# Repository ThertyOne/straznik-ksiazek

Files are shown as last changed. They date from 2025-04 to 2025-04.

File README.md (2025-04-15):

# Strażnik książek – Mechatroniczny Trzymacz Książek

Projekt realizowany w ramach kursu **Systemy elektroniczne w mechatronice** na Politechnice Wrocławskiej.

## 📚 Opis projektu

**Strażnik książek** to inteligentny trzymacz książek w formie figurki Iron-Mana, który reaguje na obecność użytkownika oraz warunki otoczenia. Urządzenie integruje różne technologie mechatroniczne, takie jak:

- Wykrywanie ruchu (czujnik PIR)
- Detekcja obecności książek (fotorezystor)
- Pomiar światła dziennego (fotorezystor)
- Podświetlenie LED (WS2812)
- Ruchoma głowa figurki (serwo MG90S)
- Efekty dźwiękowe (DFPlayer Mini + głośnik)

## ⚙️ Wykorzystane komponenty

- **Mikrokontroler**: Arduino Nano V3.0  
- **Czujniki**: PIR HC-SR505, 2x fotorezystor GL5616  
- **Wykonawcze**: serwomechanizm MG90S, listwa LED WS2812 (2x po 8 diod)  
- **Dźwięk**: DFPlayer Mini + głośnik 1W 8Ω  
- **Zasilanie**: 5V/2A (gniazdo DC barrel)  

## 💡 Funkcjonalność

1. Detekcja ruchu użytkownika aktywuje system.
2. Sprawdzana jest obecność książek oraz poziom światła dziennego.
3. Jeśli książki są obecne i jest ciemno:
   - Włączane jest podświetlenie LED.
   - Głowa figurki porusza się w stronę użytkownika.
   - Odtwarzany jest losowy dźwięk Iron-Mana (MP3 z karty SD).

System automatycznie się dezaktywuje przy braku ruchu.

## 🧠 Kod i biblioteki

Kod Arduino wykorzystuje następujące biblioteki:

- `Servo.h` – sterowanie serwem  
- `Adafruit_NeoPixel.h` – sterowanie LED WS2812  
- `SoftwareSerial.h` – komunikacja z DFPlayer Mini  
- `DFRobotDFPlayerMini.h` – obsługa odtwarzacza MP3

## 📦 Zawartość repozytorium

- `kod.ino` – kod źródłowy dla Arduino
- `schematy/` – schematy elektroniczne (.sch, .brd)
- `3d/` – modele 3D (.stl, .step)
- `bom.csv` – lista komponentów (Bill of Materials)
- `dokumentacja.pdf` – pełna dokumentacja projektowa
- `rysunki_złożeniowe.pdf` – wizualizacje montażu

## 👤 Autor

**Dominik Bukowicz**

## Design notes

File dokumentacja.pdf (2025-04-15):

## Politechnika Wroc lawska

## Wydzia l Elektroniki, Fotoniki i Mikrosystemów

# Stra żnik ksia żek

## Dokumentacja projektowa

Imie i nazwisko:
Dominik Bukowicz
Nr indeksu:
268519

Kurs:
Systemy elektroniczne w mechatronice

### Wroc law, kwiecień 2025

## Contents

1 Za lo żenia koncepcyjne i projektowe | 2
2 Schemat blokowy urzadzenia | 3
3 Opis dzia lania urzadzenia | 4
4 Opis symulacji konwertera logicznego (Rx) | 5
5 P lyta PCB realizujaca funkcje sterujaca (4 warstwy) | 7
6 Schemat blokowy kodu | 8
7 Instrukcja u żytkownika i uruchomienia | 10
8 Instrukcja serwisowa | 12
9 Widoki modelu 3D urzadzenia | 14
Dodatek A – Rysunki z lo żeniowe | 17
Dodatek B – Schemat elektroniczny uk ladu | 20
Dodatek C – Widok poszczególnych wartsw p lytki PCB | 22

## 1. Za lo żenia koncepcyjne i projektowe

Projekt ma na celu stworzenie mechatronicznego trzymacza ksiażek opartego o mikrokontroler Arduino Nano, inspirowanego postacia Iron-Mana. G lówne funkcjonalności to:

- Detekcja obecności użytkownika (PIR),
- Detekcja obecności ksiażek (fotorezystor),
- Detekcja świat la dziennego (fotorezystor),
- Oświetlenie LED (16 diod WS2812),
- Ruchoma g lowa (serwo MG90S),
- Odtwarzanie dźwieków (DFPlayer mini + g lośnik),
- System dezaktywuje sie, gdy nie ma ksiażek lub jest jasno.

Dla zapewnienia prawid lowej pracy ca lego systemu dobrano zasilanie 5V o wydajności pradowej do 2A poprzez z lacze typu DC barrel. Szacunkowe zużycie pradu przez poszczególne komponenty przedstawia Tabela 1. Maksymalny pobór pradu przy jednoczesnym dzia laniu serwomechanizmu, odtwarzacza DFPlayer oraz listw LED może wynie´sć nawet do 1,5–1,7 A, dlatego wybrano zasilacz zapewniajacy odpowiedni zapas bezpieczeństwa. Zastosowany zasilacz (5V/2A) zapewnia stabilno´sć pracy oraz możliwo´sć dalszej rozbudowy systemu.

Table 1: Szacowany pobór pradu przez komponenty systemu

Komponent | Pobór pradu
Arduino Nano V3.0 | do 200 mA
Serwo MG90S (w ruchu) | 120–250 mA (maks. 700 mA)
2x listwa LED WS2812 (16 diod) | ok. 220 mA (maks. do 960 mA)
DFPlayer Mini + g lośnik | do 200 mA
Czujnik PIR HC-SR505 | < 0,1 mA
Fotorezystory (2 szt., przez dzielniki napiecia) | pomijalne (µA)
Lacznie (typowo) Lacznie (szczytowo) | 800–950 mA do ok. 1,7 A

## 2. Schemat blokowy urzadzenia

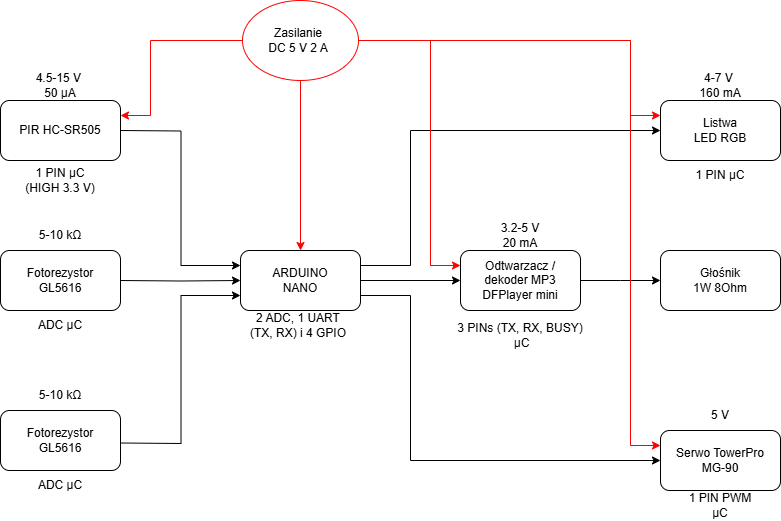
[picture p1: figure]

Figure 1: Schemat blokowy systemu

## 3. Opis dzia lania urzadzenia

Urzadzenie rozpoczyna swoje dzia lanie po wykryciu obecności użytkownika za pomoca czujnika ruchu PIR HC-SR505. Detekcja ruchu inicjuje sekwencje sprawdzania stanu otoczenia oraz warunków, w których aktywacja efektów ma sens i spe lnia za lożenia projektowe.
Pierwszym etapem po detekcji ruchu jest weryfikacja obecności ksiażek – realizowana przy pomocy fotorezystora (GL5616) umieszczonego w pokrywie trzymacza. W przypadku braku ksiażek urzadzenie nie podejmuje dalszych dzia lań.
Jeśli ksiażki sa obecne, system przechodzi do oceny warunków oświetleniowych – fotorezystor (GL5616) monitoruje poziom świat la dziennego. Jeżeli oświetlenie otoczenia przekracza ustalony próg (np. w ciagu dnia), funkcje urzadzenia pozostaja nieaktywne, by uniknać niepotrzebnego dzia lania.

W momencie, gdy spe lnione sa dwa podstawowe warunki:
- Obecno´sć ksiażek
- Brak świat la dziennego

Nastepuje aktywacja urzadzenia:

1. W lacza sie podświetlenie LED – listwa WS2812 w podstawie urzadzenia podświetla ksiażki efektownym, kolorowym świat lem (pomarańczowym).
2. Mechanizm obrotowy wprawia w ruch g lowe modelu Iron-Mana, wykonujac symboliczny gest interakcji.
3. DFPlayer Mini losowo wybiera i odtwarza jeden z wcześniej wgranych plików dźwiekowych w formacie MP3 – kwestie g losowe inspirowane postacia Iron-Mana (jedna z 5 losowych kwestii).

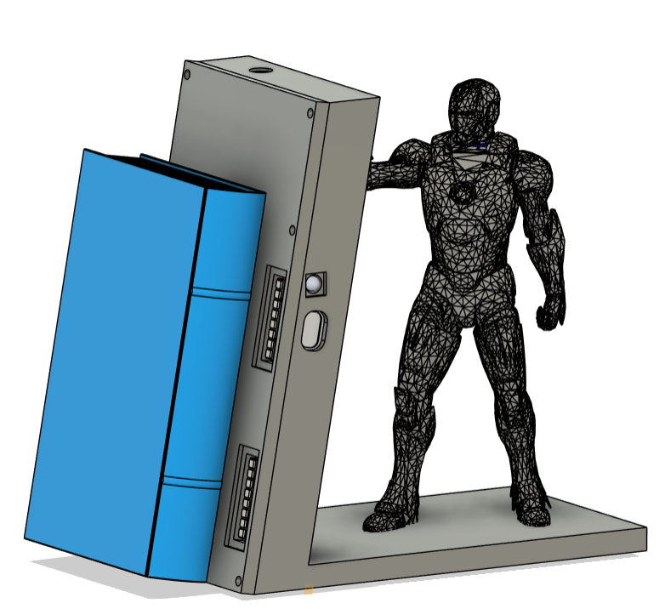
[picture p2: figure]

Figure 2: Schemat blokowy systemu

## 4. Opis symulacji konwertera logicznego (Rx)

W celu zapewnienia poprawnej komunikacji pomiedzy Arduino Nano (pracujacym z logika 5 V) a modu lem DFPlayer Mini (obs lugujacym poziomy logiczne 3,3 V), konieczne by lo dopasowanie poziomów napieć dla linii transmisji UART.
W celu konwersji logiki 3,3 V na logike 5 V zastosowano klasyczny uk lad logicznego konwertera poziomów napieć oparty na tranzystorze BSS138, dzia lajacy jako prze lacznik typu open-drain. Umożliwia on komunikacje pomiedzy urzadzeniami pracujacymi na różnych poziomach logicznych, zapewniajac niezawodna i bezpieczna dwukierunkowa transmisje danych bez ryzyka uszkodzenia modu lu DFPlayer Mini.
Dodatkowo, do jednostronnej konwersji (dla linii Tx Arduino → Rx DFPlayer) wykorzystano dzielnik napiecia zbudowany z rezystorów, który redukowa l napiecie z 5 V do oko lo 3,3 V.

### 4.1. Odbiór danych z DFPlayera:

Modu l DFPlayer Mini, oprócz odbierania komend sterujacych, może również wysy lać dane zwrotne przez swoja linie Tx (czyli Rx Arduino). Przyk ladowe dane to informacje o rozpoczeciu lub zakończeniu odtwarzania, kody b ledów (np. brak karty SD, nieprawid lowy format pliku), a także odpowiedzi na zapytania — np. aktualny poziom g lośności, numer odtwarzanego utworu czy liczba dostepnych plików.
Odbieranie tych danych może być kluczowe podczas debugowania kodu. Pozwala to na weryfikacje poprawności komunikacji UART, sprawdzenie, czy komendy sa prawid lowo interpretowane przez modu l oraz szybkie diagnozowanie problemów zwiazanych z dzia laniem DFPlayera lub karta pamieci. Dzieki temu możliwe jest precyzyjniejsze dostosowanie logiki programu do realnych warunków pracy uk ladu podczas debugownia kodu.
Poniżej znajduje sie schemat symulowanego uk ladu w programie LTspice, a także wynik przeprowadzonej symulacji, potwierdzajacy poprawno´sć dzia lania konwertera poziomów logicznych.

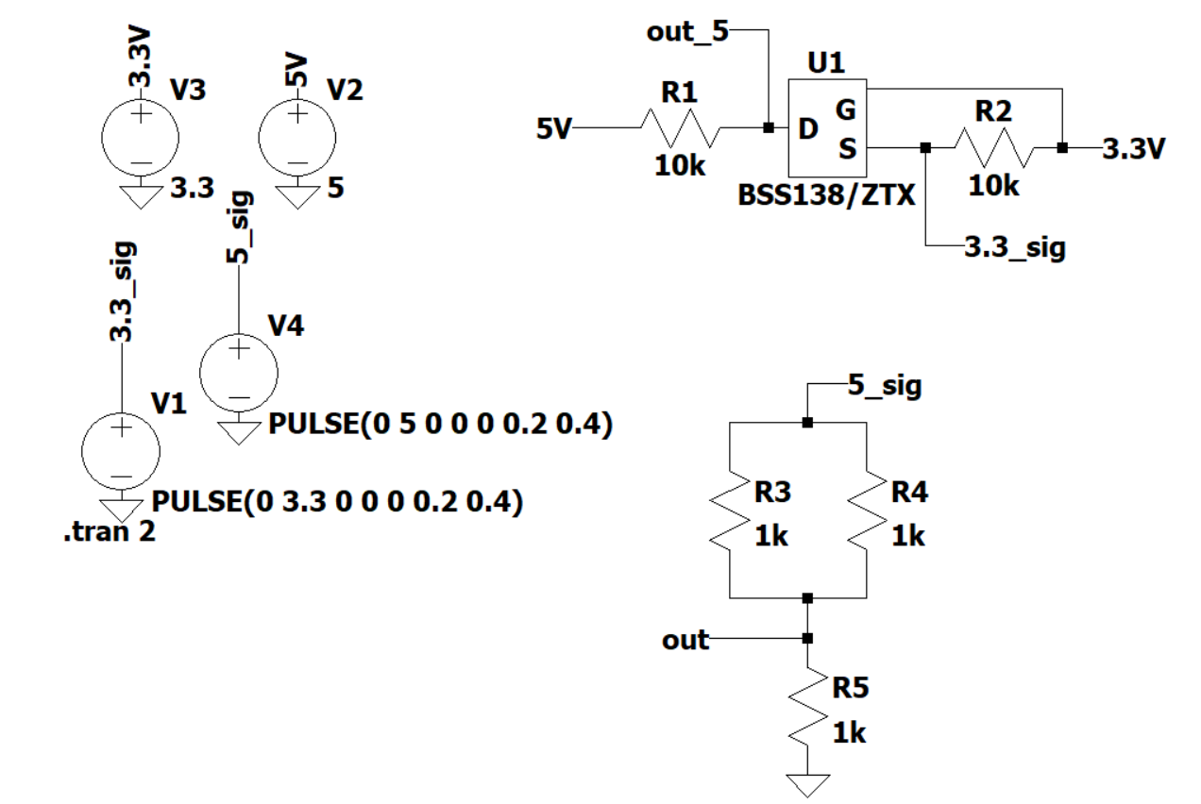
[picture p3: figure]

Figure 3: Symulacja konwertera logicznego Rx

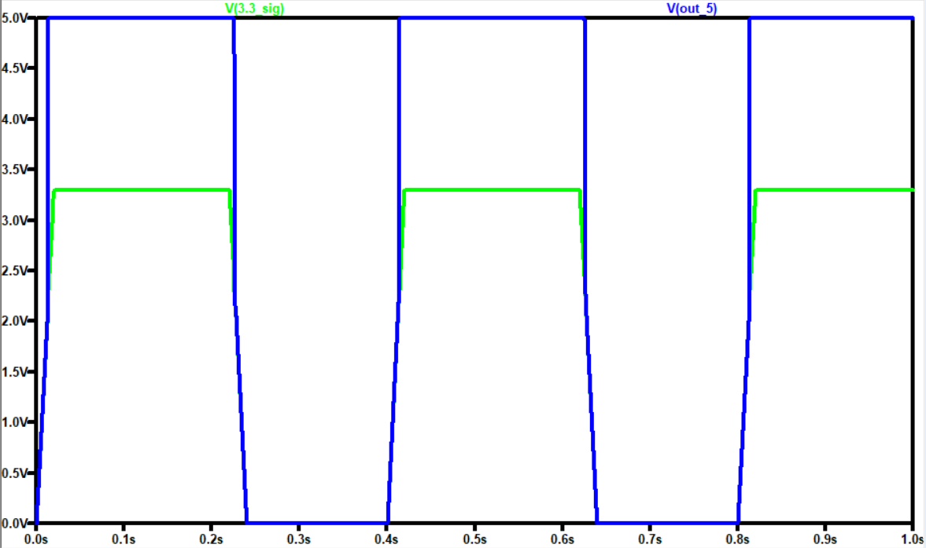
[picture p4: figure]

Figure 4: Wynik symulacji - napiecia Rx

## 5. P lyta PCB realizujaca funkcje sterujaca (4 warstwy)

W ramach integracji sygna lów z peryferiów oraz zapewnienia odpowiedniego reagowania systemu na zdarzenia zgodnie z za lożeniami projektowymi, zaprojektowano i wykonano czterowarstwowa p lytke PCB. Jej zadaniem jest po laczenie wszystkich kluczowych elementów systemu, takich jak mikrokontroler, czujniki, modu ly wykonawcze oraz komponenty zasilajace, w jeden spójny uk lad.
Cztery warstwy pozwoli ly na rozdzielenie sygna lów, zasilania oraz masy, co znaczaco poprawi lo integralno´sć sygna lu i zminimalizowa lo zak lócenia elektromagnetyczne (EMI). Zasilanie ca lego uk ladu realizowane jest poprzez zewnetrzny zasilacz 5V o wydajności pradowej 2A, co zapewnia odpowiednia rezerwe mocy nawet przy równoczesnym zasilaniu elementów o wiekszym poborze pradu, takich jak serwomechanizm MG90S, listwy LED WS2812 czy modu l DFPlayer Mini. Na p lytce zaprojektowano odpowiednie ścieżki i punkty rozdzia lu napiecia, a także uwzgledniono kondensatory filtrujace w celu stabilizacji pracy uk ladu i redukcji zak lóceń.
Na p lytce umieszczono z lacza do pod laczenia serwomechanizmu, listwy LED, czujnika PIR, fotorezystorów, DFPlayera oraz innych komponentów. Uwzgledniono również możliwo´sć programowania mikrokontrolera bez konieczności demontażu systemu oraz zaprojektowano p lytke tak, by umożliwia la latwy montaż mechaniczny wewnatrz obudowy urzadzenia.

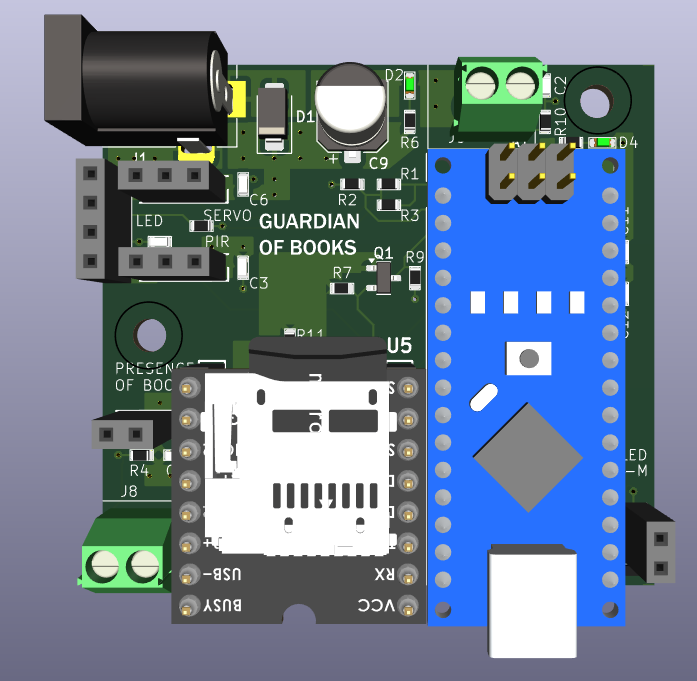
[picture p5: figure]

Figure 5: Model 3D p lytki obwodów drukowanych

## 6. Schemat blokowy kodu

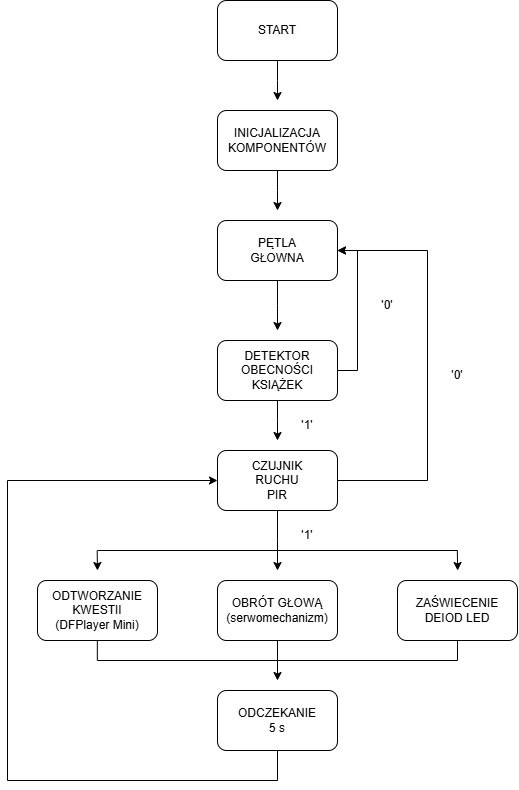
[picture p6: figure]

Figure 6: Schemat blokowy kodu

Kod wykorzystuje biblioteki:

- Servo.h – sterowanie serwem,
- Adafruit NeoPixel.h – sterowanie LED WS2812,
- SoftwareSerial.h – komunikacja z DFPlayer Mini,
- DFRobotDFPlayerMini.h – wybór i odtwarzanie plików MP3.

G lówne funkcje kodu:

- Odczyt z czujników (PIR, fotorezystory),
- Warunkowe w laczanie LED, serwa i dźwieku,
- Komunikacja z odtwarzaczem MP3.

## 7. Instrukcja u żytkownika i uruchomienia

Niniejsza instrukcja opisuje sposób poprawnego uruchomienia oraz użytkowania mechatronicznego trzymacza ksiażek w formie figurki Iron-Mana. Urzadzenie dzia la autonomicznie po prawid lowym zasileniu oraz spe lnieniu warunków środowiskowych.

1. Zasilanie: Pod lacz zasilacz 5V 2A do gniazda DC typu barrel znajdujacego sie z boku ścianki pionowej urzadzenia.
2. Karta microSD: Upewnij sie, że karta microSD zosta la poprawnie w lożona do gniazda DFPlayer Mini i zawiera poprawnie nazwane foldery:
- Nazwy folderów: 01, 02, 03, ...
- Pliki wewnatrz folderów: 001.mp3, 002.mp3, ...

Pliki dźwiekowe musza być zapisane w formacie MP3, WAV lub WMA.

3. Pozycjonowanie ksia żek: Umie´sć co najmniej jedna ksiażke na trzymaczu, zas laniajac czujnik obecności ksiażek (fotorezystor umieszczony w ściance trzymacza).
4. Uruchomienie systemu: Podejdź do urzadzenia w odleg lości poniżej 1 m. Czujnik PIR wykryje ruch użytkownika i aktywuje system.
5. Przebieg dzia lania po aktywacji:
- Sprawdzany jest poziom świat la dziennego — jeżeli jest ciemno, za laczane sa diody LED do oświetlenia ksiażek.
- Sprawdzana jest obecno´sć ksiażek – brak obecności dezaktywuje system.
- Serwomechanizm obraca g lowa Iron-Mana w kierunku użytkownika.
- DFPlayer Mini odtwarza losowa kwestie Iron-Mana z dostepnych plików.
6. Dezaktywacja: Po wykryciu braku ruchu w otoczeniu (ok. 5 sekund bez sygna lu z czujnika PIR), system automatycznie przechodzi w stan spoczynku:
- Wy laczane jest oświetlenie LED,
- Serwomechanizm wraca do pozycji poczatkowej,
- Odtwarzanie zostaje zakończone.
7. Bezpieczne wy laczenie: Aby wy laczyć system, należy od laczyć zasilacz 5V DC. Nie należy wy laczać urzadzenia przez od laczanie pojedynczych przewodów ani przez gwa ltowne ruchy.
8. Uwaga: Podczas aktualizacji oprogramowania (wgrywania kodu do Arduino Nano przez USB), zewnetrzne zasilanie 5V musi być od laczone, aby uniknać uszkodzenia portu USB lub mikrokontrolera.

Zalecenia dla u żytkownika:

- Nie należy narażać urzadzenia na dzia lanie wilgoci ani wysokich temperatur.

- Nie należy manipulować przy czujnikach ani przewodach podczas dzia lania systemu.
- Ruchome elementy (np. g lowa figurki) powinny mieć zapewniona przestrzeń do swobodnego poruszania sie.
- System nie jest przystosowany do pracy ciag lej – zaleca sie jego wy laczenie na noc lub podczas d luższej nieobecności.

## 8. Instrukcja serwisowa

Urzadzenie wymaga okresowej kontroli pod wzgledem poprawności dzia lania oraz czystości po laczeń mechanicznych i elektrycznych. Poniżej przedstawiono zalecane czynności serwisowe oraz instrukcje aktualizacji lub debugowania kodu na mikrokontrolerze.

### 8.1. Elementy wymagajace kontroli

- Serwomechanizm MG90S – należy upewnić sie, że mechanicznie nie jest zablokowany oraz że obrót odbywa sie p lynnie.
- Listwy LED WS2812 – należy sprawdzić, czy wszystkie diody świeca sie prawid lowo. W przypadku losowego migania może być konieczne sprawdzenie rezystora szeregowego na linii danych (330 Ω).
- DFPlayer Mini – jeżeli nie odtwarza dźwieków, należy upewnić sie, że karta microSD jest poprawnie sformatowana (FAT32), zawiera odpowiednie pliki w odpowiednich folderach oraz że linie komunikacyjne TX/RX nie sa uszkodzone.
- Czujniki PIR i fotorezystory – moga ulec zabrudzeniu lub uszkodzeniu mechanicznemu. Warto okresowo sprawdzić ich reakcje na zmiany w otoczeniu (ruch/świat lo).
- Po laczenia GND i 5V – należy skontrolować, czy wszystkie przewody zasilajace i masy sa dobrze przylutowane lub pewnie umocowane w z laczach.
- Zasilanie 5V (2A) – w przypadku niestabilnego dzia lania uk ladu (np. restart Arduino, niedzia lajace diody LED) należy zmierzyć napiecie wyjściowe zasilacza oraz sprawdzić, czy jego wydajno´sć pradowa jest wystarczajaca.
- Zasilanie - należy sprawdzić czy wszystkie diody sygnalizujace napiecie zasilania świeca prawid lowo (5V, 5V Arduino, 3.3V).

### 8.2. Procedura ladowania lub debugowania kodu

Do wgrania nowego kodu na Arduino Nano lub jego debugowania należy:

1. Od laczyć zewnetrzne zasilanie 5V DC!
2. Pod laczyć komputer do Arduino Nano za pomoca kabla USB (microUSB).
3. W środowisku Arduino IDE wybrać odpowiedni port COM oraz p lytke (Arduino Nano, procesor ATmega328P, bootloader ”Old Bootloader” jeśli wymagany).
4. Za ladować kod klikajac Upload.
5. Po zakończeniu wgrywania od laczyć kabel USB i dopiero wtedy ponownie pod laczyć zasilanie 5V DC.

Uwaga: Jednoczesne pod laczenie zasilania zewnetrznego oraz USB może prowadzić do uszkodzenia komputera lub p lytki Arduino, ponieważ może doj´sć do konfliktu napieć na linii VCC.

### 8.3. Uwagi końcowe

W razie konieczności wymiany jakiegokolwiek elementu należy zachować szczególna ostrożno´sć podczas lutowania oraz unikać zwarć przy ponownym montażu. Wszystkie naprawy należy wykonywać przy od laczonym zasilaniu. Zaleca sie przeprowadzenie pe lnego testu systemu po każdej naprawie lub aktualizacji oprogramowania.

## 9. Widoki modelu 3D urzadzenia

Model 3D przedstawia figure Iron Mana o wysokości 25–30 cm, trzymajaca pionowa ścianke pe lniaca funkcje podpórki na ksiażki. Postać ma wyciagnieta d loń ustawiona pod katem oko lo 90 stopni, co zapewnia stabilne podparcie konstrukcji. Wzd luż ramienia zosta l zaprojektowany tunel umożliwiajacy poprowadzenie przewodów zasilajacych i sterujacych do serwomechanizmu, ukrytego wewnatrz korpusu figury.
G lowa postaci jest ruchoma w zakresie 0–90 stopni dzieki zastosowaniu serwomechanizmu MG90S, zintegrowanego z korpusem. Wewnatrz g lowy wydrażono gniazdo dopasowane do profilu zebatki serwa, co umożliwia bezpośrednie po laczenie z jego osia – bez potrzeby stosowania dodatkowych mocowań. Ca ly mechanizm zosta l dyskretnie ukryty pod elementem imitujacym bark i szyje, co pozwala zachować spójno´sć wizualna modelu i jednocześnie zapewnia precyzje oraz stabilno´sć ruchu.
Pionowa ścianka wspierajaca ksiażki jest zintegrowana z podstawa, w której przewidziano miejsce na p lytke PCB oraz inne komponenty elektroniczne. Pokrywa ścianki zawiera otwory na diody LED oraz czujnik obecności ksiażek, a ca lo´sć zamyka estetyczna pokrywka mocowana za pomoca śrub. Projekt laczy elementy dekoracyjne z praktycznymi rozwiazaniami technicznymi, tworzac zarówno funkcjonalny, jak i wizualnie atrakcyjny element wyposażenia.

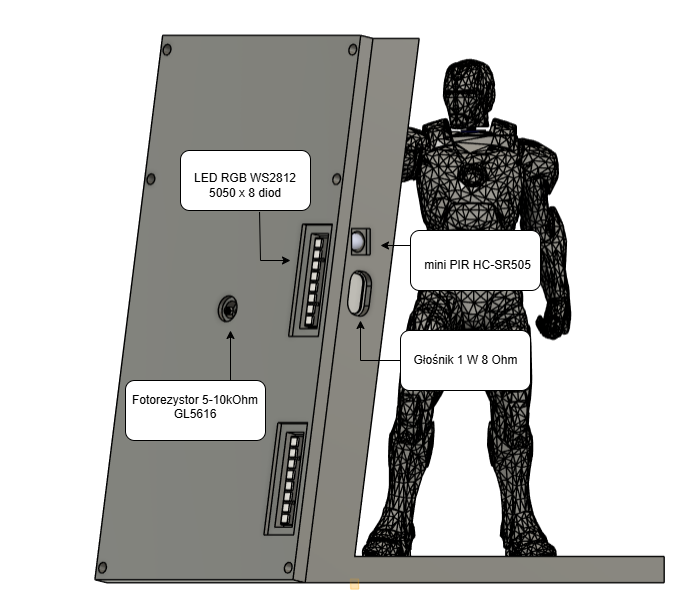
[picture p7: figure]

Figure 7: Widok modelu 3D z objaśnieniem elementów projektu (1)

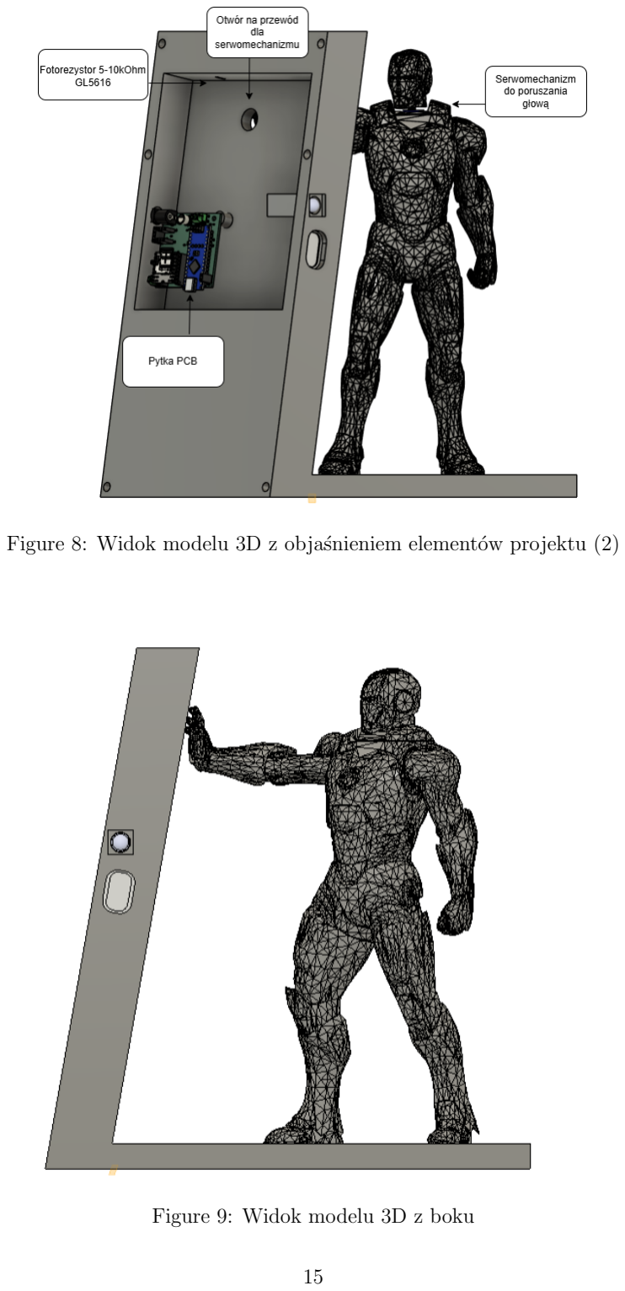
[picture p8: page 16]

Figure 8: Widok modelu 3D z objaśnieniem elementów projektu (2)

Figure 9: Widok modelu 3D z boku

## Za laczniki

- Plik BOM (.csv),
- Kod programu (.ino),
- Pliki 3D (.stl, .step),
- Schematy elektryczne (.sch, .brd),
- Biblioteki wykorzystanych elementów elektronicznych (.kicadsym, .pretty),
- Noty katalogowe kluczowych elementów (.pdf),
- Rysunki z lożeniowe (.pdf).

## Dodatek A – Rysunki z lo żeniowe

Schemat montażowy uk ladu zosta l przedstawiony na ilustracji 10, bedacej wizualizacja modelu 3D p lytki PCB. Na rysunku zaznaczono miejsca pod laczenia wszystkich g lównych przewodów sygna lowych oraz zasilajacych. Czerwone kwadraty na modelu oznaczaja dedykowane punkty GND dla poszczególnych peryferiów.

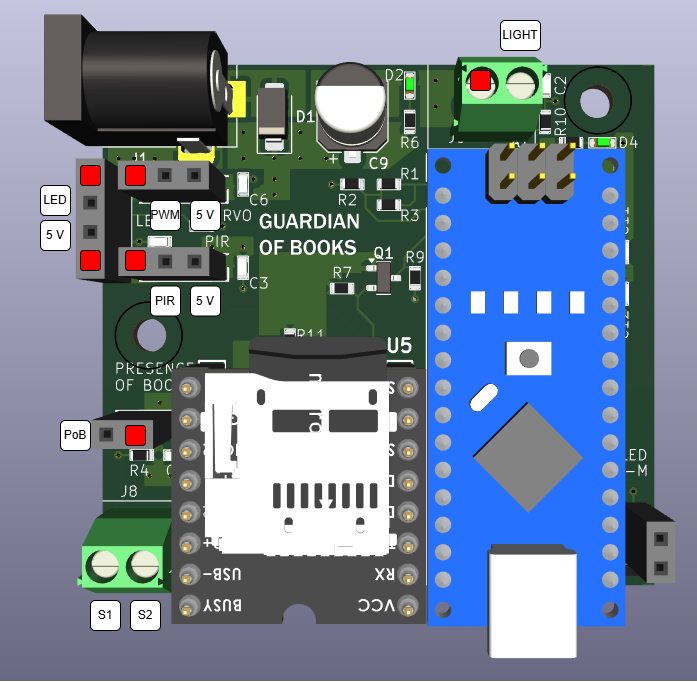
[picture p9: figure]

Figure 10: Model 3D PCB z oznaczeniami wyprowadzeń

W poniższej tabeli przedstawiono zestawienie peryferiów oraz opis ich wymaganych wyprowadzeń:

Peryferium | Wyprowadzenia
Serwo MG90S Listwy LED WS2812 (2x) Czujnik PIR HC-SR505 G lośnik 1W 8Ω Fotorezystor (ksiażki) Fotorezystor (świat lo dzienne) | PWM (D9), 5V, GND LED (D6), 5V, GND PIR (D2), 5V, GND SPK1, SPK2 PoB, GND LIGHT, GND

Table 2: Zestawienie wyprowadzeń dla peryferiów

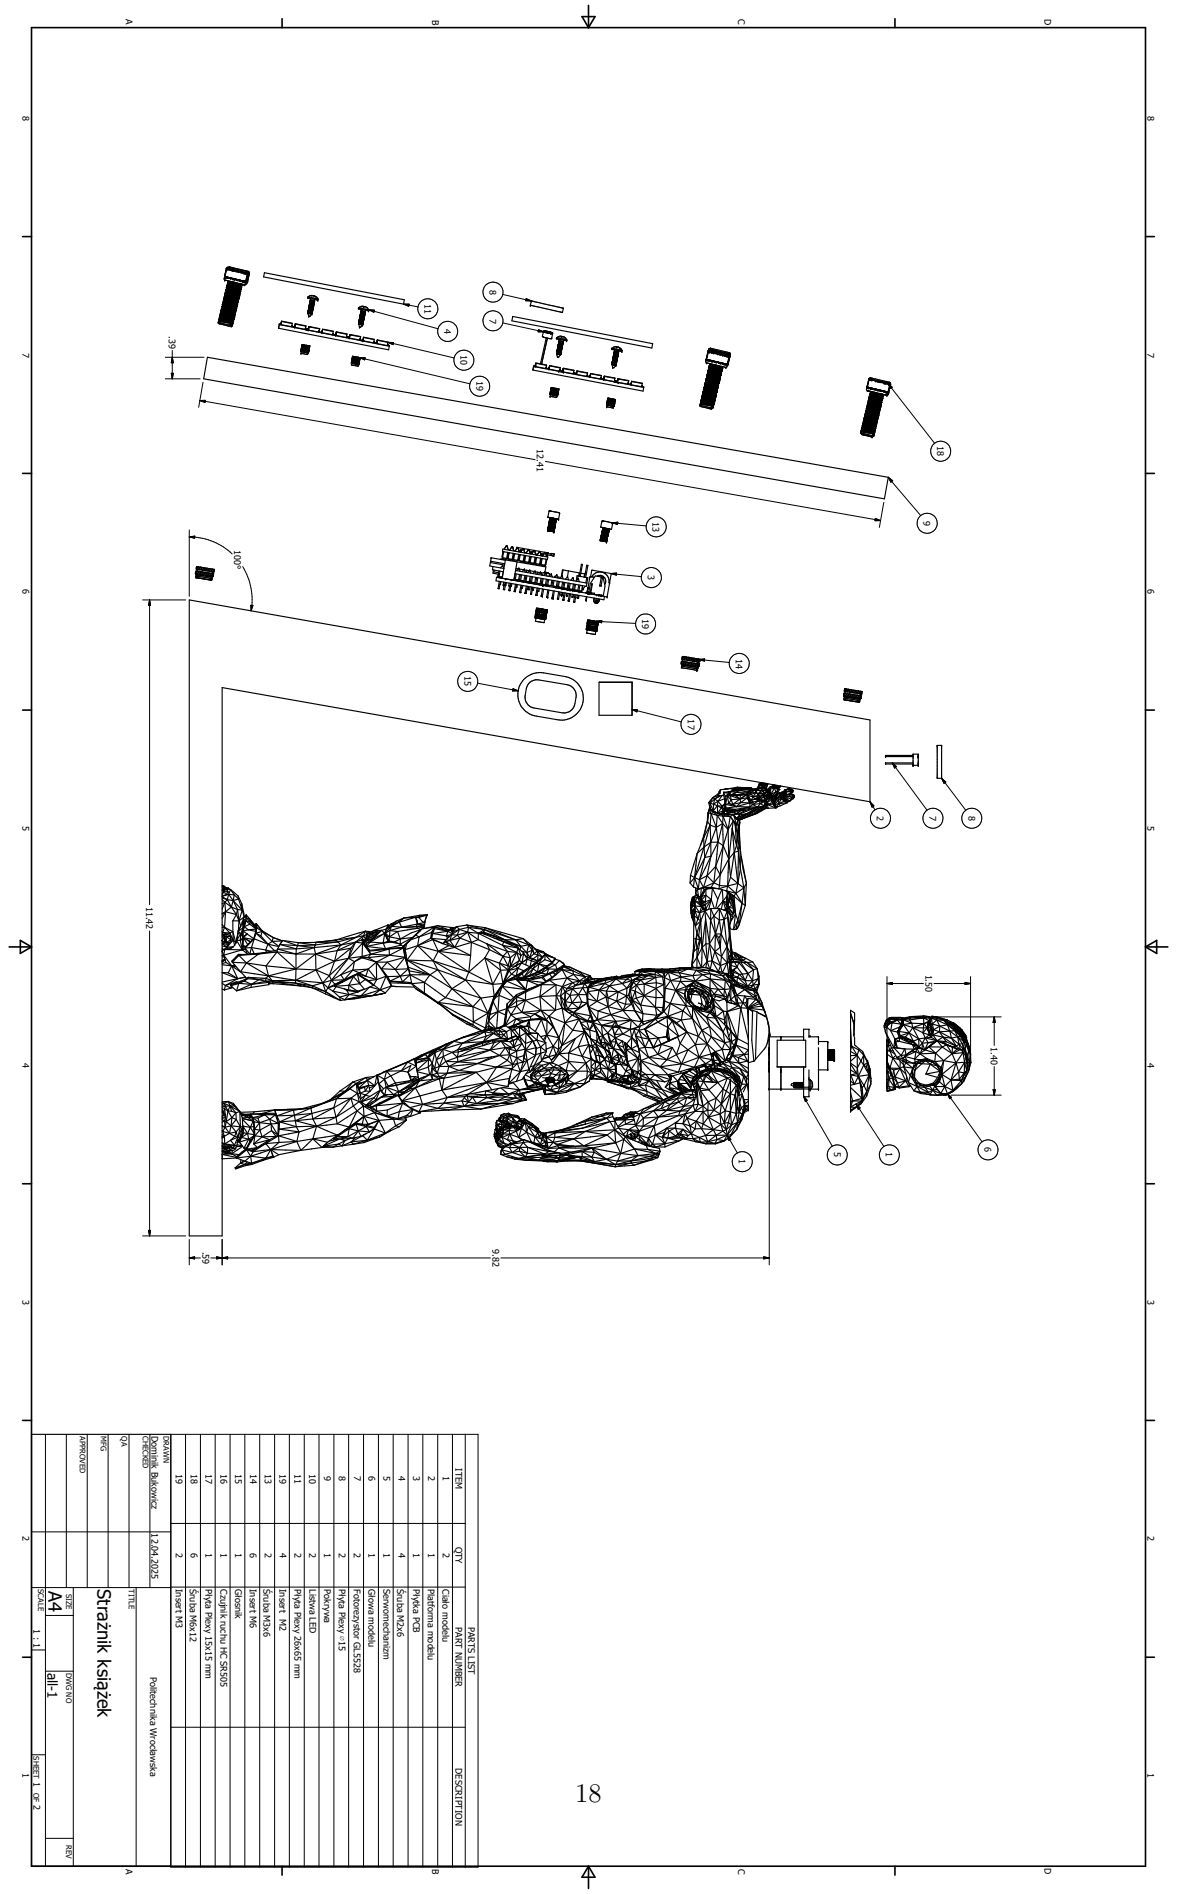
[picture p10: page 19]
PARTS LIST; Ciało modelu 2 1; Platforma modelu 1 2; Płytka PCB 1 3; Śruba M2x6 4 4; Serwomechanizm 1 5; Głowa modelu 1 6; Fotorezystor GL5528 2 7; Płyta Plexy ∅15 2 8; Pokrywa 1 9; Listwa LED 2 10; Insert M2 4 19; Śruba M3x6 2 13; Insert M6 6 14; Głosnik 1 15; Śruba M6x12 6 18; Insert M3 2 19; SHEET 1 OF 2; APPROVED; MFG; CHECKED; Dominik Bukowicz 12.04.2025; DRAWN; all-1; DWG NO; Strażnik książek; TITLE; A4 SIZE; SCALE; Politechnika Wrocławska; REV

Płyta Plexy 15x15 mm 1 17

Czujnik ruchu HC SR505 1 16

Płyta Plexy 26x65 mm 2 11

DESCRIPTION PART NUMBER QTY ITEM

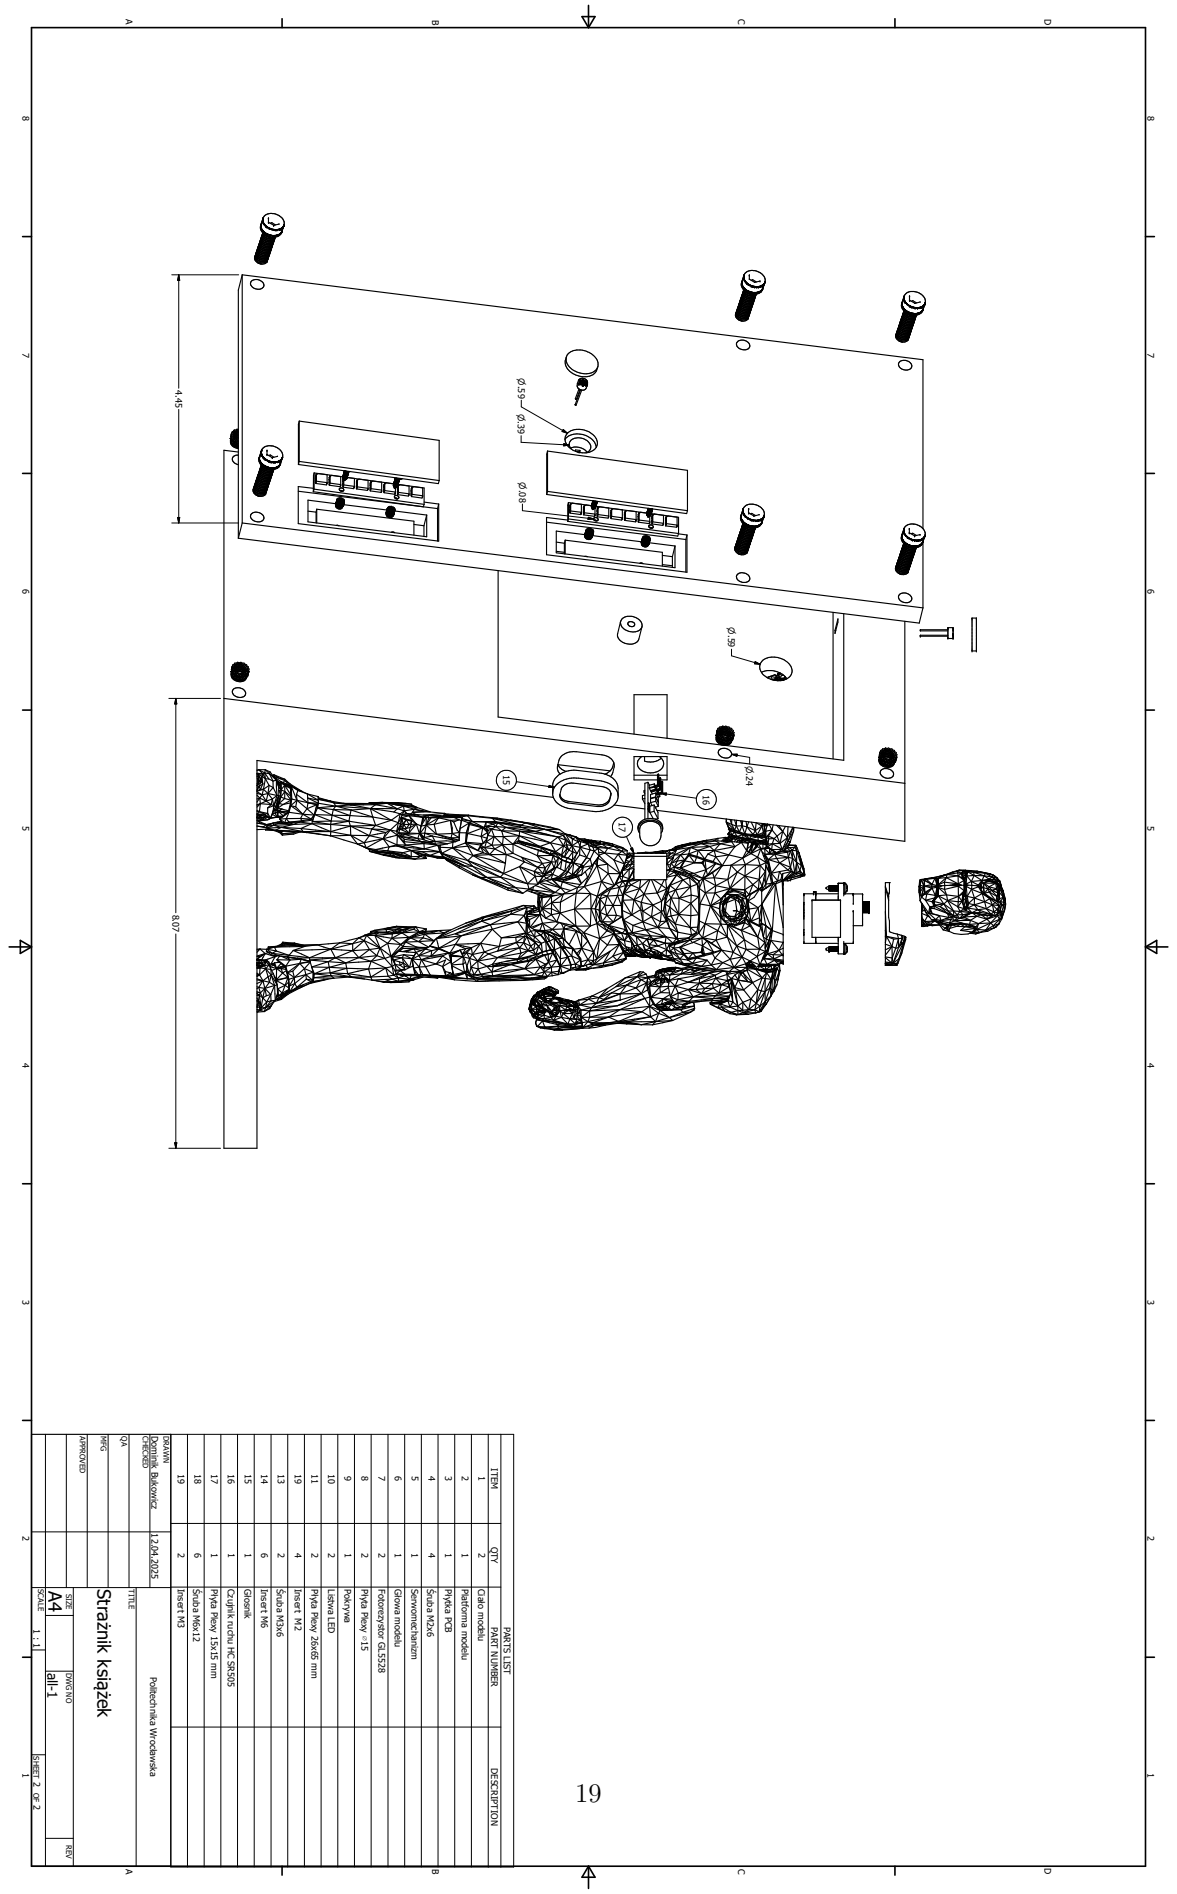
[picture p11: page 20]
SHEET 2 OF 2; APPROVED; MFG; CHECKED; Dominik Bukowicz 12.04.2025; DRAWN; all-1; DWG NO; Strażnik książek; TITLE; A4 SIZE; SCALE; Politechnika Wrocławska; REV; PARTS LIST; Ciało modelu 2 1; Platforma modelu 1 2; Płytka PCB 1 3; Śruba M2x6 4 4; Serwomechanizm 1 5; Głowa modelu 1 6; Fotorezystor GL5528 2 7; Płyta Plexy ∅15 2 8; Pokrywa 1 9; Listwa LED 2 10; Insert M2 4 19; Śruba M3x6 2 13; Insert M6 6 14; Głosnik 1 15; Śruba M6x12 6 18; Insert M3 2 19

Płyta Plexy 15x15 mm 1 17

Czujnik ruchu HC SR505 1 16

Płyta Plexy 26x65 mm 2 11

DESCRIPTION PART NUMBER QTY ITEM

## Dodatek B – Schemat elektroniczny uk ladu

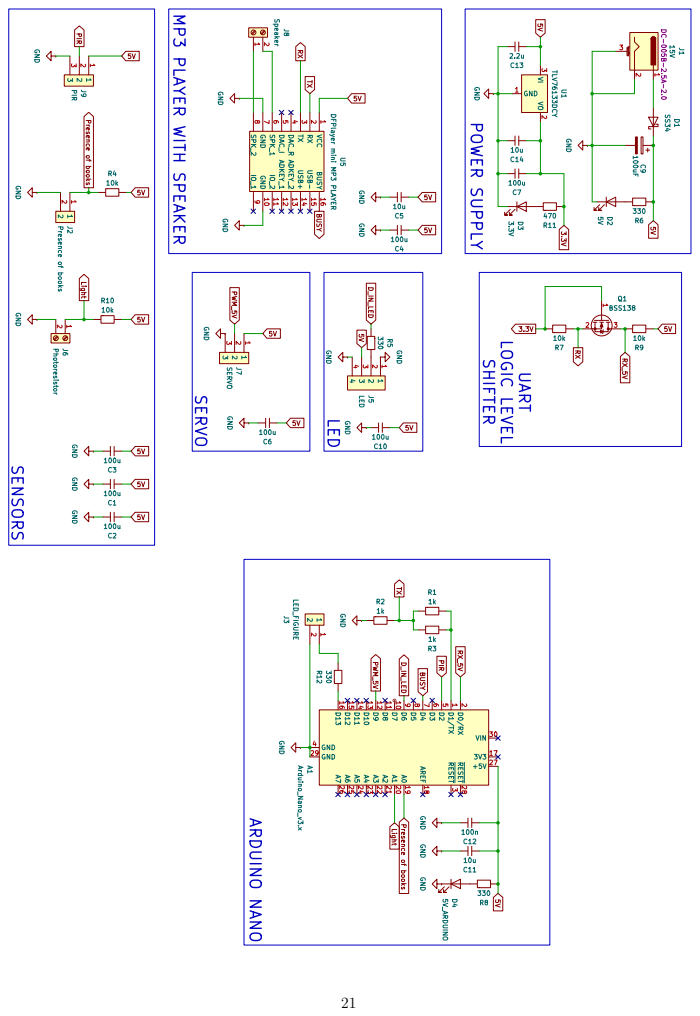
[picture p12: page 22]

## Dodatek C – Widok poszczególnych wartsw p lytki PCB

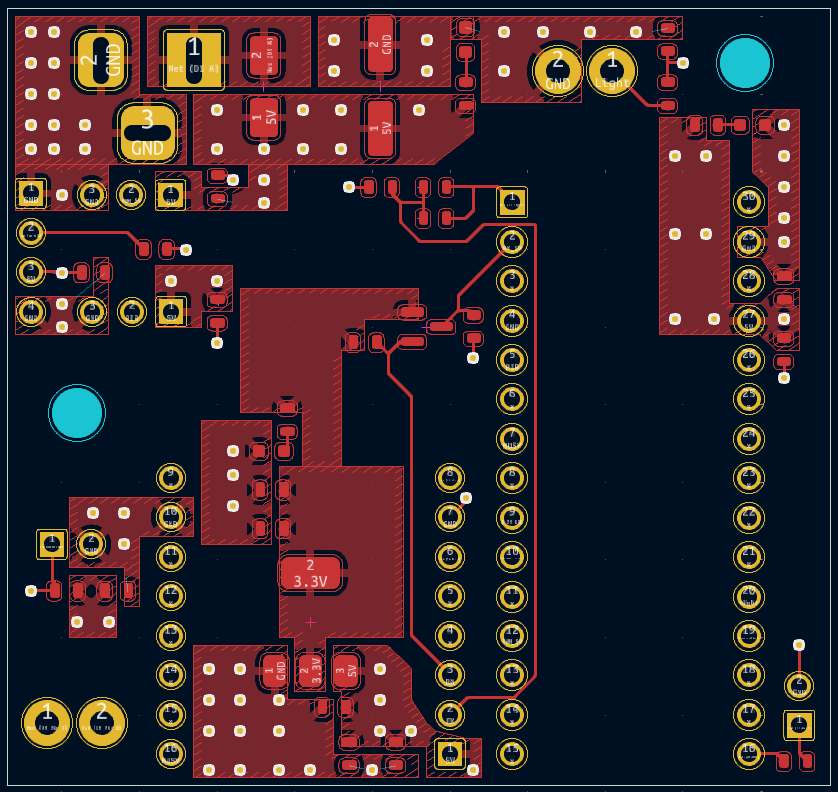
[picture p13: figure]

Figure 11: Warstwa sygna lowa (top)

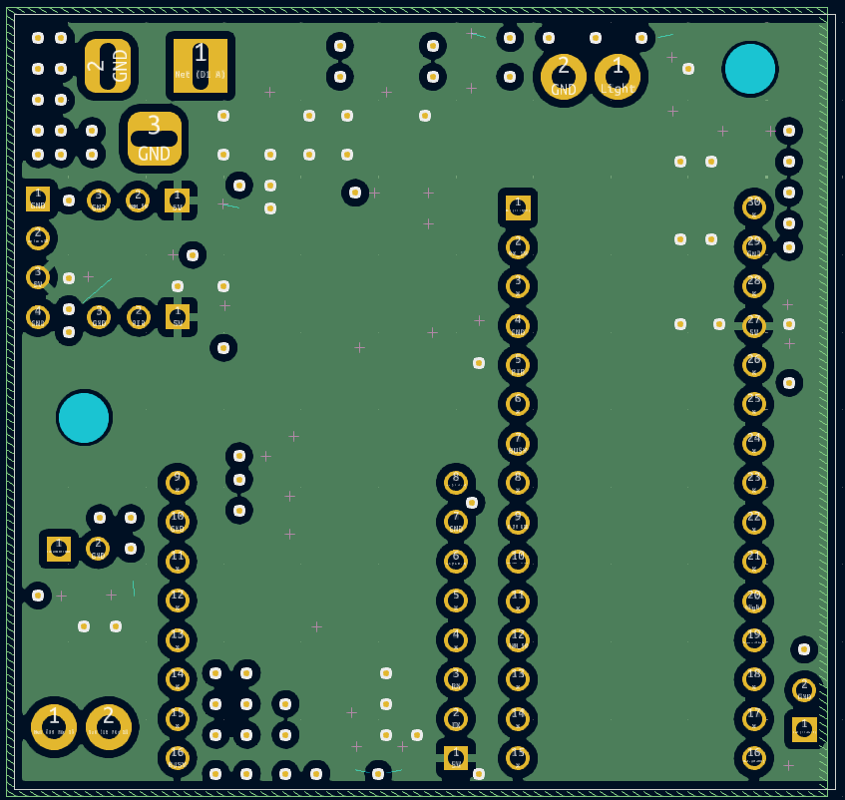
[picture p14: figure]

Figure 12: Warstwa zasilajaca 5V

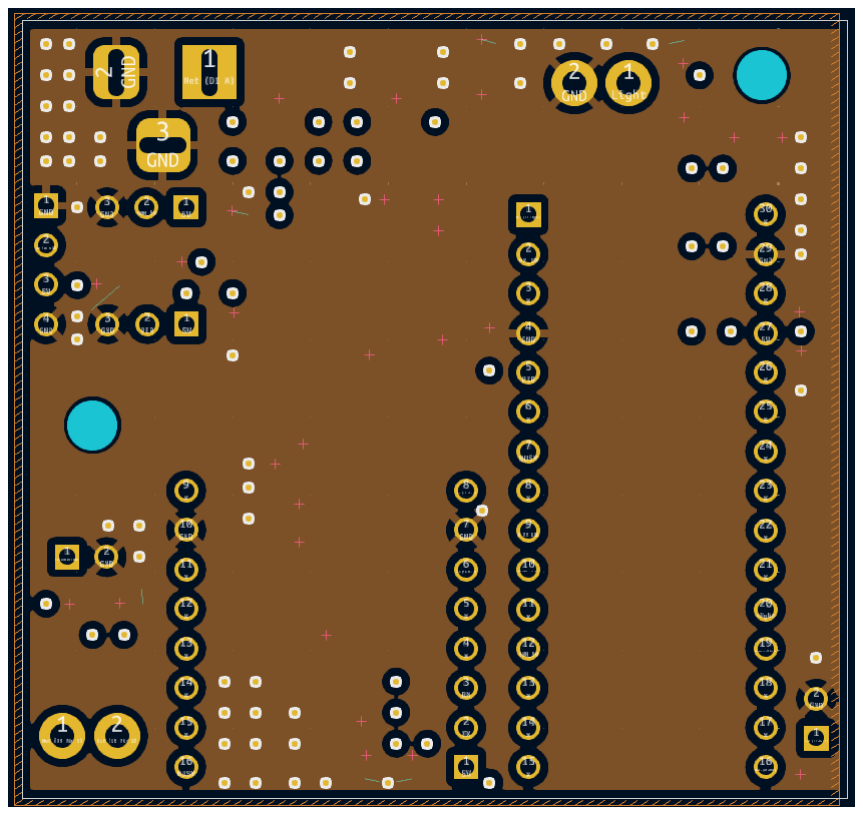
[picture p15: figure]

Figure 13: Warstwa GND

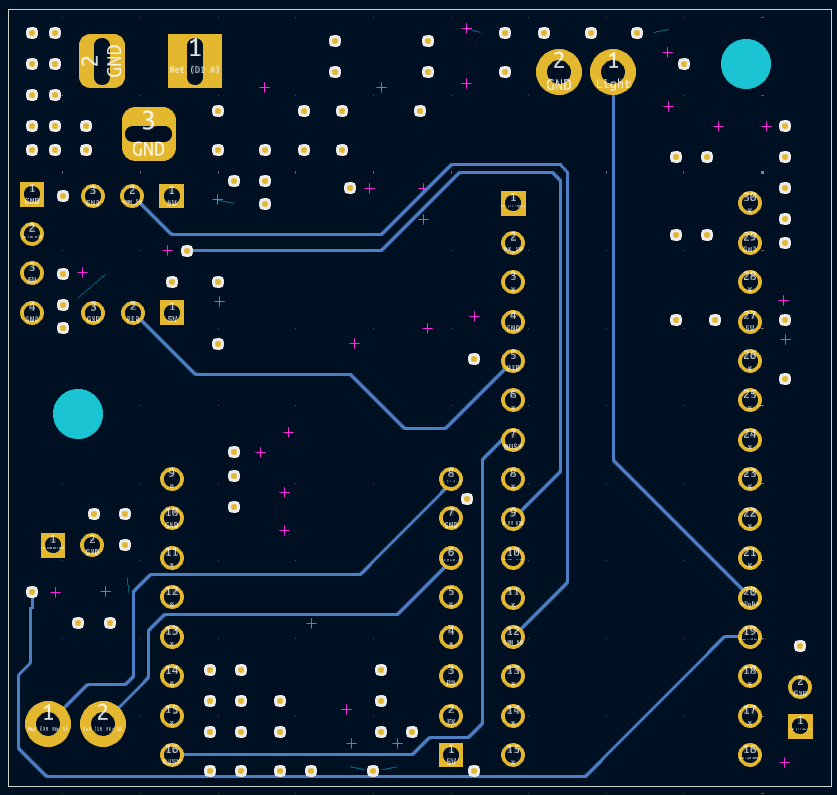
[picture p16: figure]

Figure 14: Warstwa sygna lowa (bottom)

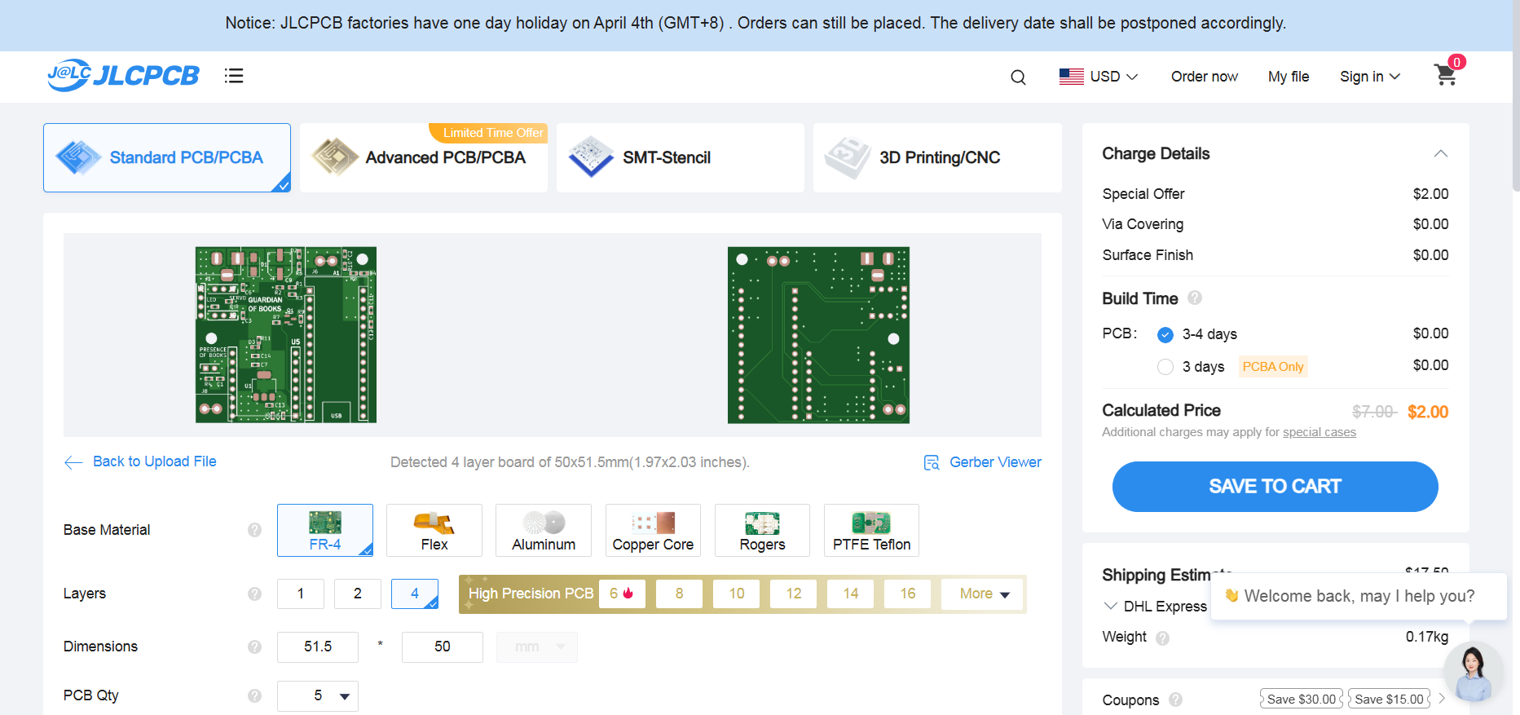
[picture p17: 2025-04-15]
JPCLB _zamownie.png

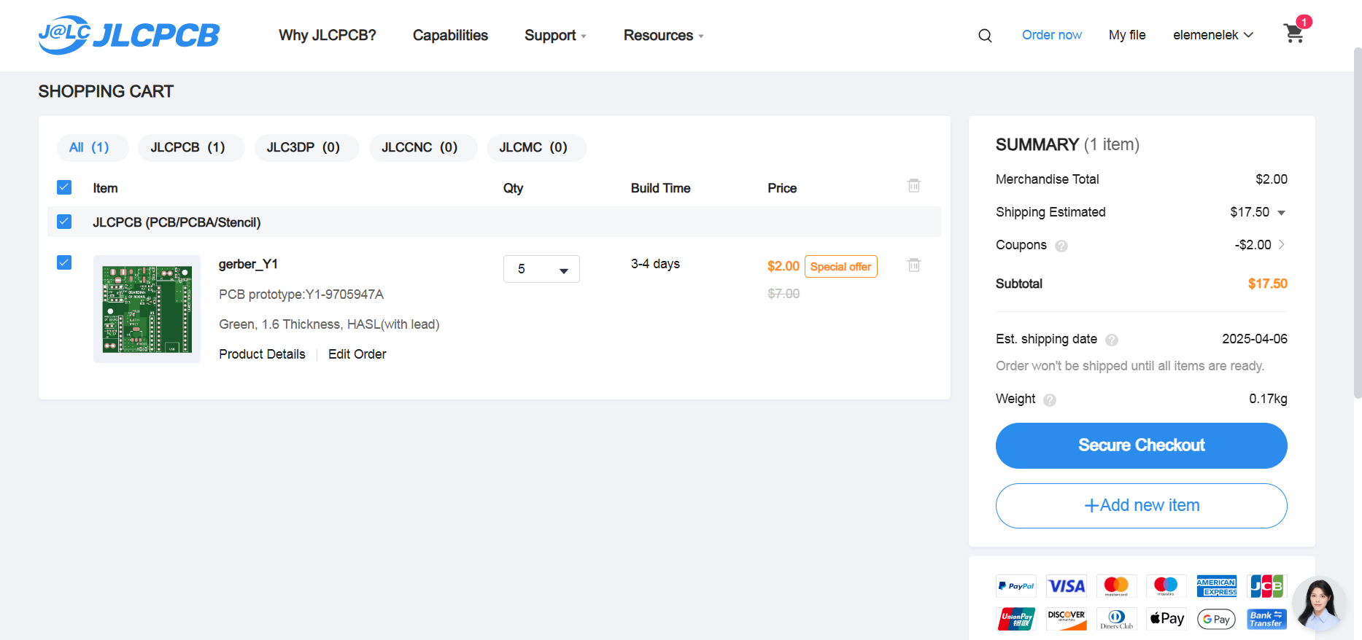
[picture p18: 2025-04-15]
JPCLB_z_wysylka.png

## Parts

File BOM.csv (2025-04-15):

Nr. | Oznaczenie | Footprint | Ilo?? | Nazwa / numer seryjny | Warto?? | Tolerancja | Cena za szt. [z?] | URL
1 | R11 | res_0603 | 1 | RC0603FR-07470RP | 470 | ±1% | 0,39 | https://www.digikey.pl/pl/products/detail/yageo/RC0603FR-07470RP/4935414?productid=4935414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
2 | R12,R6,R5,R8 | res_0603 | 4 | RC0603JR-13330RL | 330 | ±5% | 0,39 | https://www.digikey.pl/pl/products/detail/yageo/RC0603JR-13330RL/14287581?productid=14287581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
3 | R1,R2,R3 | res_0603 | 3 | RC0603FR-131KL | 1k | ±1% | 0,39 | https://www.digikey.pl/pl/products/detail/yageo/RC0603FR-131KL/12756423?productid=12756423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
4 | R4,R9,R10,R7 | res_0603 | 4 | RC0603FR-13330KL | 10k | ±1% | 0,39 | https://www.digikey.pl/pl/products/detail/yageo/RC0603FR-13330KL/14287759?productid=14287759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
5 | C6,C4,C3,C1,C7,C2,C10 | cap_0603 | 7 | GRM31CR60J107KEA8L | 100u | ±10% | 0,46 | https://www.digikey.com/en/products/detail/murata-electronics/GRM31CR60J107KEA8L/16286000
6 | C13 | cap_0603 | 1 | C0603C225K4PACTU | 2.2u | ±10% | 0,47 | https://www.digikey.pl/pl/products/detail/kemet/C0603C225K4PACTU/3471609?productid=3471609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
7 | C11,C14,C5 | cap_0603 | 3 |  | 10u | ±20% | 1,6 | https://www.mouser.pl/ProductDetail/TDK/C1608X5R1E106M080AC?qs=dfay7wIA1uGdHfZTkqsICA%3D%3D
8 | C12 | cap_0603 | 1 | C0603C104M5REC7411 | 100n | ±20% | 0,53 | https://www.mouser.pl/ProductDetail/KEMET/C0603C104M5REC7411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
9 | C9 | CP_Elec_6.3x7.7 | 1 | EEE-FN1V101XP | 100uF | ±20% | 2,45 | https://www.mouser.pl/ProductDetail/Panasonic/EEE-FN1V101XP?qs=OlC7AqGiEDmbk%2FCOXeagbw%3D%3D
10 | D1 | D_SMA | 1 |  | SS34 |  | 4,45 | https://www.tme.eu/en/details/ss34-cdi/smd-schottky-diodes/cdil/ss34/
11 | D2, D3, D4 | LED_SMD | 3 |  | 5V |  | 3,21 | https://www.tme.eu/pl/details/of-smd2012g/diody-led-smd-kolorowe/optoflash/
12 | J1 | BarrelJack_Horizontal | 1 | PJ-102B | 15V |  | 2,29 | https://www.mouser.pl/ProductDetail/Same-Sky/PJ-102B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
13 | J2, J3, J5, J7, J9, U5 | pin_con_10_female | 3 |  |  |  | 4,52 | https://www.mouser.pl/ProductDetail/Harwin/M20-7820646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
14 | J8, J6 | screw_conector | 2 | Listwa zaciskowa |  |  | 1,85 | https://www.tme.eu/pl/details/282837-2/listwy-zaciskowe-do-druku/te-connectivity/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
15 | U1 | SOT-223-3_TabPin2 | 1 | TLV76133DCY |  |  | 1,59 | https://www.digikey.pl/en/products/detail/texas-instruments/TLV76133DCYR/18716472
16 | Q1 | SOT-23 | 1 | BSS138 |  |  | 0,97 | https://www.tme.eu/pl/details/bss138wh6327xtsa1/tranzystory-z-kanalem-n-smd/infineon-technologies/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
17 | - | DFPlayer Mini | 1 | DFPlayer Mini |  |  | 27,9 | https://botland.com.pl/odtwarzacze-mp3-wav-ogg-midi/3170-dfplayer-mini-odtwarzacz-mp3-z-gniazdem-microsd-6959420902521.html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
18 | A1 | Arduino_Nano | 1 | Arduino_Nano_v3.x |  |  | 19,9 | https://sklep.msalamon.pl/produkt/nano-v3-0-z-usb-c-zgodny-z-arduino/?gad_source=1
19 | - | servo | 1 | MG-90 - micro - 180 |  |  | 17,9 | https://botland.com.pl/serwa-typu-micro/20436-serwo-mg-90s-micro-180-stopni-plastikowa-przekladnia-5904422380922.html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
20 | - | listwa LED | 2 | LED RGB WS2812 5050 x 8 diod - 53mm |  |  | 15,9 | https://botland.com.pl/lancuchy-i-matryce-led/6255-listwa-led-rgb-ws2812-5050-x-8-diod-53mm-5903351249157.html
21 | - | glosnik 8 Ohm | 1 | G?o?nik 1 W 8 Ohm |  |  | 11,9 | https://botland.com.pl/czujniki-ruchu/5862-czujnik-ruchu-mini-pir-hc-sr505-5904422359669.html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
22 | - | fotorezystor | 2 | Fotorezystor 5-10k? GL5616 |  |  | 4,9 | https://botland.com.pl/glosniki-analogowe/19458-glosnik-1w-8ohm-30x20x5mm-adafruit-4227-5904422354848.html
23 | - | PIR | 1 | mini PIR HC-SR505 |  |  | 9,9 | https://botland.com.pl/czujniki-ruchu/5862-czujnik-ruchu-mini-pir-hc-sr505-5904422359669.html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
24 | - | zasilacz | 1 | Zasialacz 5V 2A - DC barrle |  |  | 26,9 | https://botland.com.pl/zasilacze-dogniazdkowe/4088-zasilacz-akyga-5v2a-wtyk-dc-5521mm-5901720136244.html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
25 | - | gwinty insert do monta?u | 1 | Inserty gwintowe ró?ne rodzaje (M2, M3, M6) |  |  | 22,9 | https://botland.com.pl/pozostale-akcesoria-do-drukrek-3d/22015-mosiezny-gwint-insert-do-druku-3d-rozne-rozmiary-zestaw-100-sztuk-justpi-5904422383572.html
26 | - | sruby |  | ?ruby monta?owe M3, M6 |  |  | 49 | https://botland.com.pl/srubki-i-nakretki/23456-zestaw-srub-i-nakretek-m3m4m5m6-1000szt-5904257801784.html
27 | - | sruby |  | ?ruby monta?owe M2, M3 |  |  | 11,9 | https://botland.com.pl/srubki-i-nakretki/637-zestaw-srubek-podkladek-i-nakretek-330szt-5410329304478.html
28 | - | plexy matowe |  | P?yta plexy matowa |  |  | 49 | https://botland.com.pl/materialy-do-obrobki/20912-plexi-mleczna-wylewana-3mm-200x200mm-5szt-5907255402953.html
29 | - | plexy przezroczyste |  | P?yta plexy przezroczysta |  |  | 59,9 | https://botland.com.pl/materialy-do-obrobki/20909-plexi-przezroczysta-wylewana-5mm-200x200mm-5szt-5907255402908.html
30 | - | klej | 1 | Klej do mocowania p?yt |  |  | 4,5 | https://botland.com.pl/kleje-i-klejarki/1367-klej-kropelka-2-ml-77321060.html
 |  |  |  |  |  | SUMA | 358,35

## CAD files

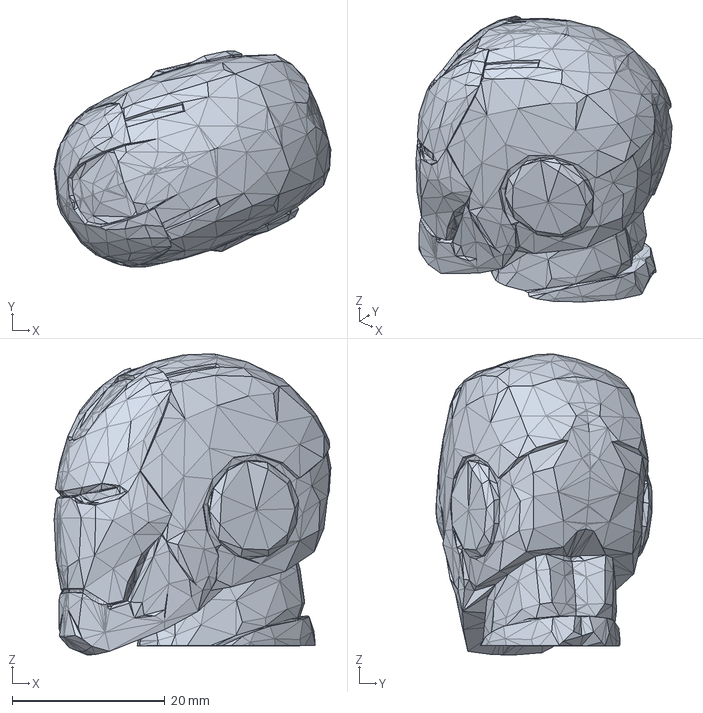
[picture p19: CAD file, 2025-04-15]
modele 3D/glowa.step
36.3 x 28.3 x 39.4 mm

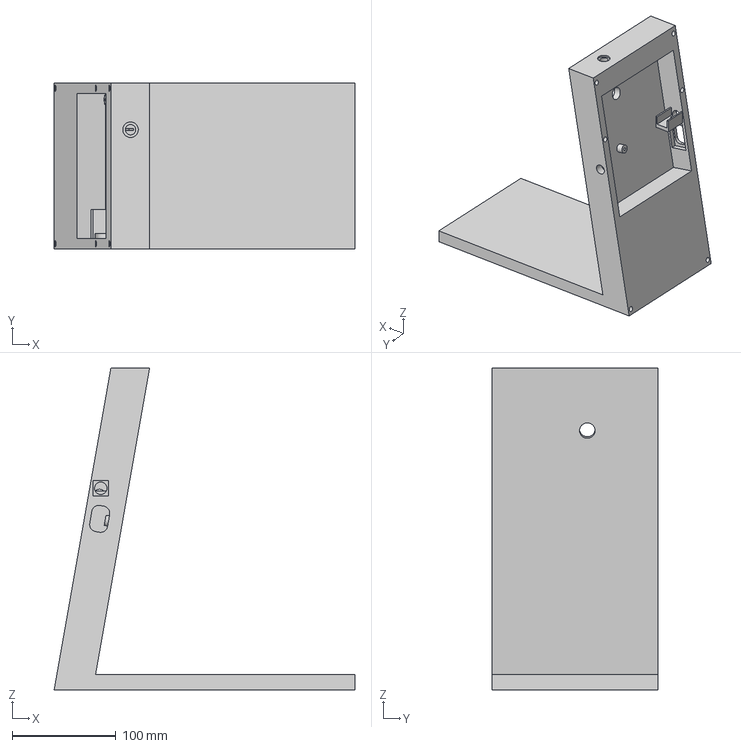
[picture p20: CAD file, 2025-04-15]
modele 3D/platforma.step
290.0 x 160.0 x 310.4 mm

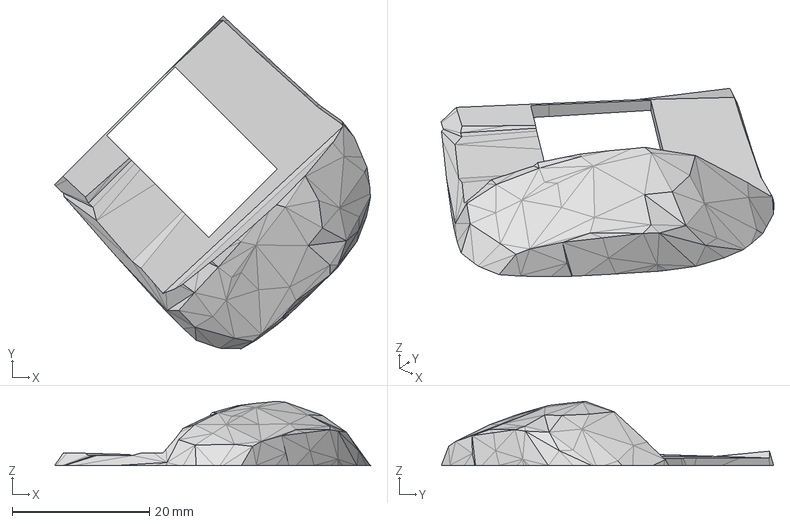
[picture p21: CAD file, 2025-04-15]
modele 3D/przykrywacz.step
46.1 x 48.5 x 9.39 mm

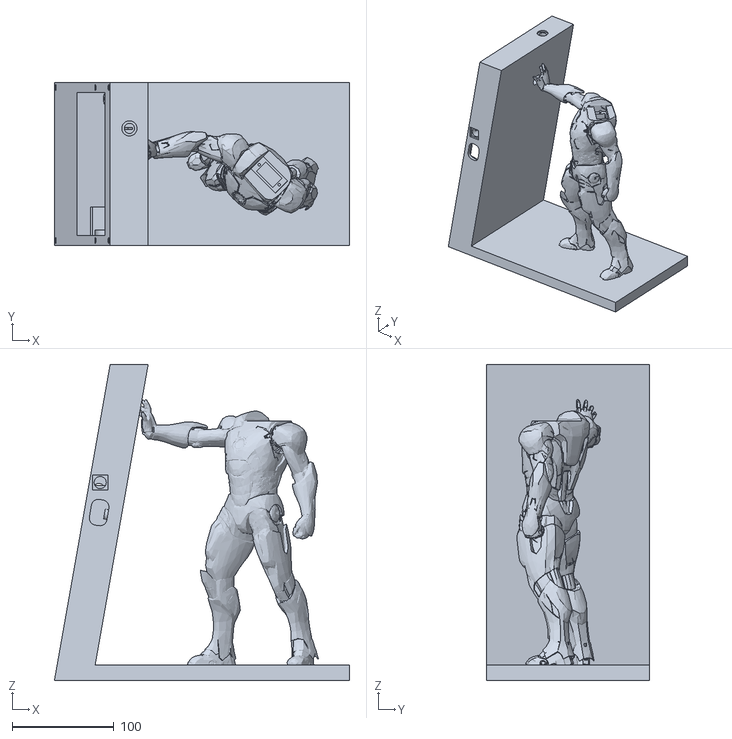
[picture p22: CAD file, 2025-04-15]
modele 3D/cialko_platforma.stl
290.0 x 160.0 x 310.4

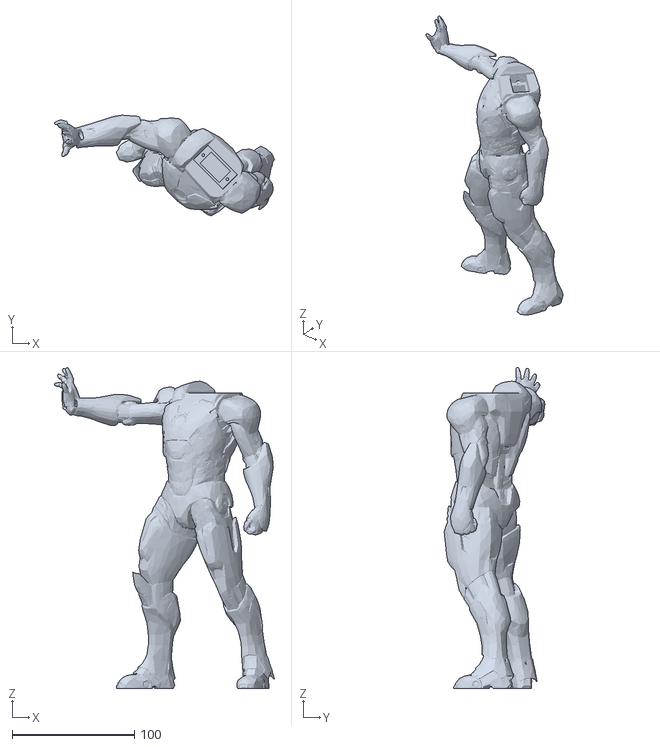
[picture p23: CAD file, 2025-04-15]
modele 3D/cialko.stl
180.0 x 82.3 x 262.6

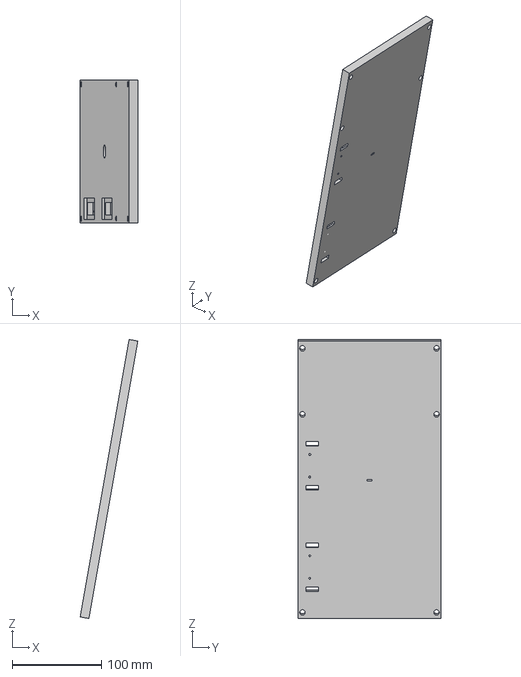
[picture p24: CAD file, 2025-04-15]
modele 3D/przykrywka.step
64.6 x 160.0 x 312.2 mm

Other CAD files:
modele 3D/glowa.stl
modele 3D/model_rysunek_zlozeniowy/Insert M2 D3.6 L4mm.ipt
modele 3D/model_rysunek_zlozeniowy/Insert M3 D5 L5mm.ipt
modele 3D/model_rysunek_zlozeniowy/LED.ipt
modele 3D/model_rysunek_zlozeniowy/M2x1.2mm Hex Nut.ipt
modele 3D/model_rysunek_zlozeniowy/M2x6.ipt
modele 3D/model_rysunek_zlozeniowy/M3 X 6mm Hex.ipt
modele 3D/model_rysunek_zlozeniowy/M6.ipt
modele 3D/model_rysunek_zlozeniowy/PLEXY 15X15.ipt
modele 3D/model_rysunek_zlozeniowy/PLEXY 15x2.ipt
modele 3D/model_rysunek_zlozeniowy/cialko_platforma.iam
modele 3D/model_rysunek_zlozeniowy/fotorezystor.iam
modele 3D/model_rysunek_zlozeniowy/glosnik.ipt
modele 3D/model_rysunek_zlozeniowy/glowa.iam
modele 3D/model_rysunek_zlozeniowy/hc sr505 movement sensor.ipt
modele 3D/model_rysunek_zlozeniowy/insert_M6_5_8.ipt
modele 3D/model_rysunek_zlozeniowy/plexy 26X65.ipt
modele 3D/model_rysunek_zlozeniowy/przykrywacz.iam
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

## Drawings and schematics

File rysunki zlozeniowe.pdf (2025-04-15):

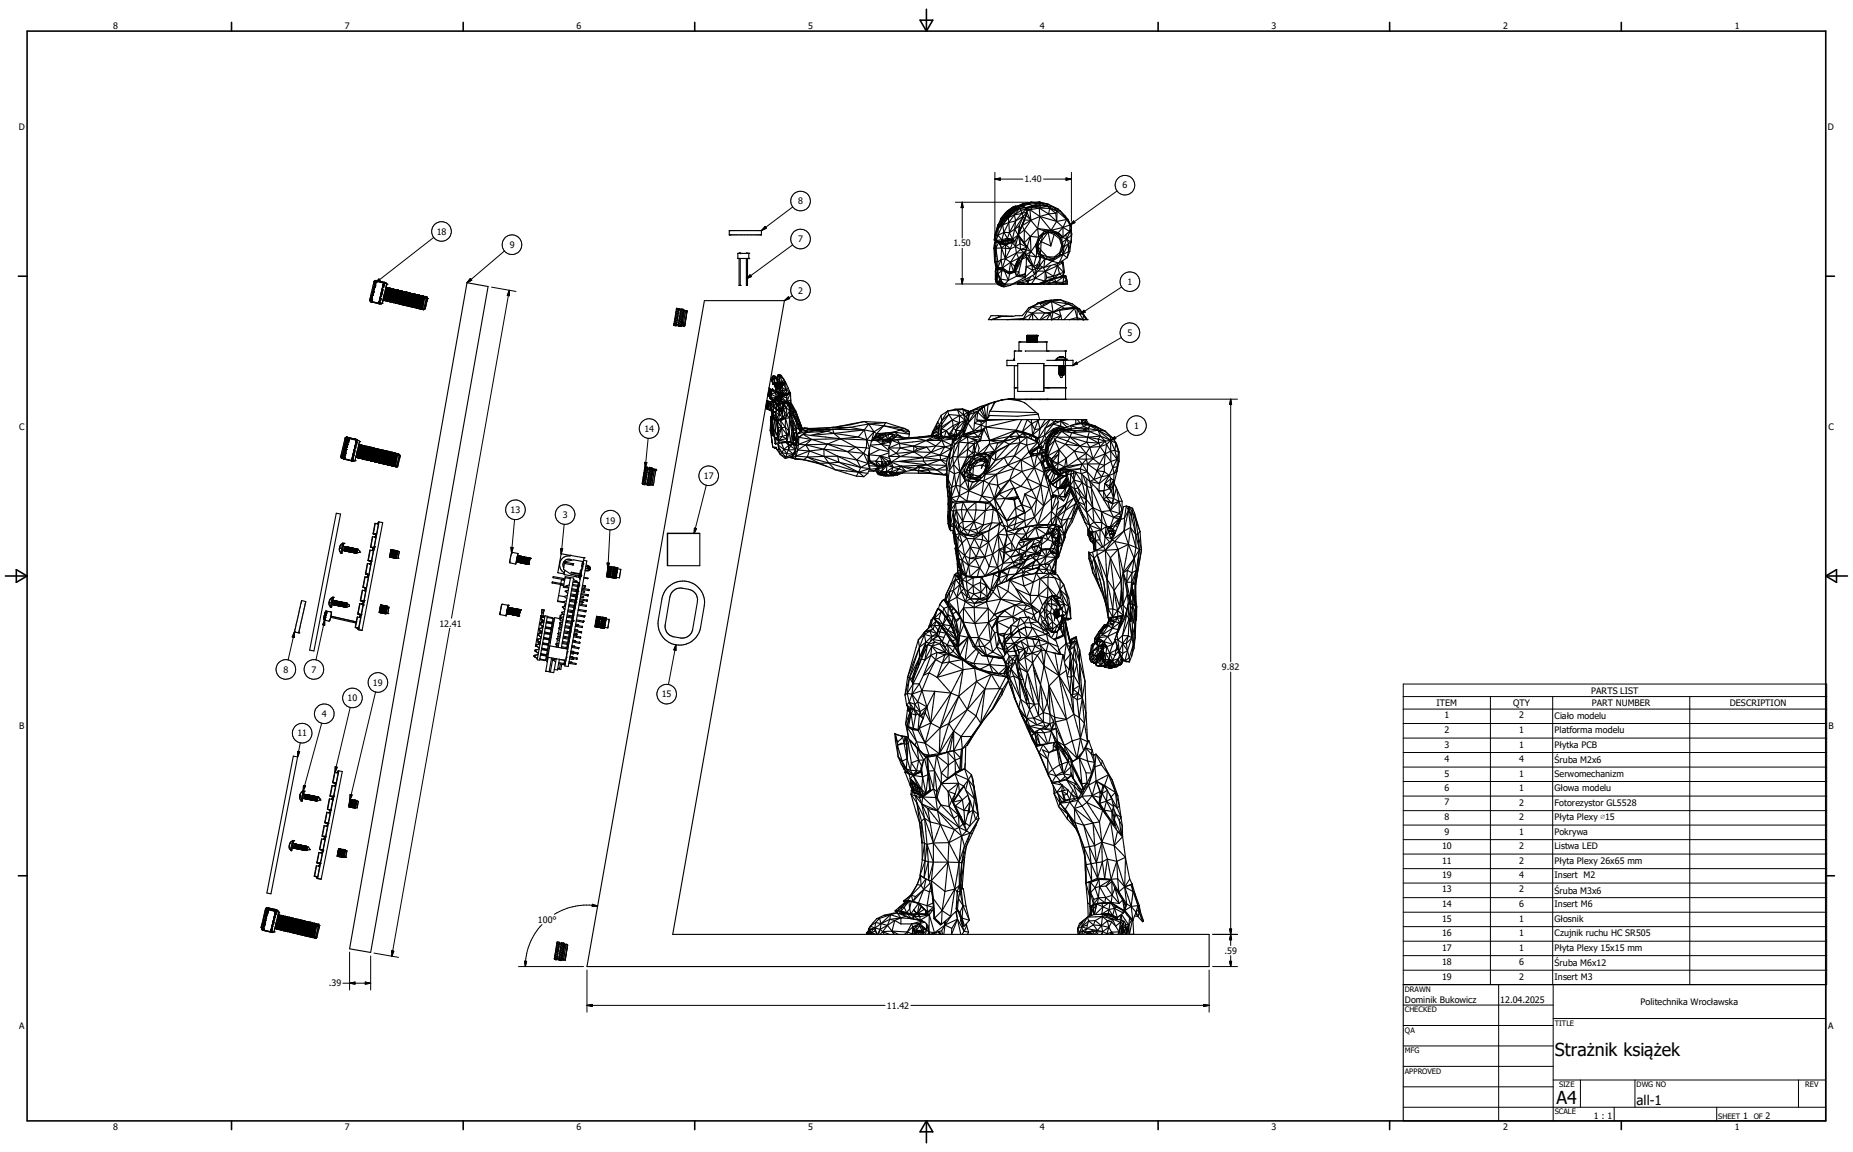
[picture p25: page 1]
PARTS LIST; ITEM; QTY; PART NUMBER; DESCRIPTION; Ciało modelu; Platforma modelu; Płytka PCB; Śruba M2x6; Serwomechanizm; Głowa modelu; Fotorezystor GL5528; Płyta Plexy ∅15; Pokrywa; Listwa LED; Płyta Plexy 26x65 mm; Insert M2; Śruba M3x6; Insert M6; Głosnik; Czujnik ruchu HC SR505; Płyta Plexy 15x15 mm; Śruba M6x12; Insert M3; SHEET 1 OF 2; DRAWN; CHECKED; MFG; APPROVED; Dominik Bukowicz; DWG NO all-1; TITLE Strażnik książek; SIZE A4; SCALE; Politechnika Wrocławska; REV

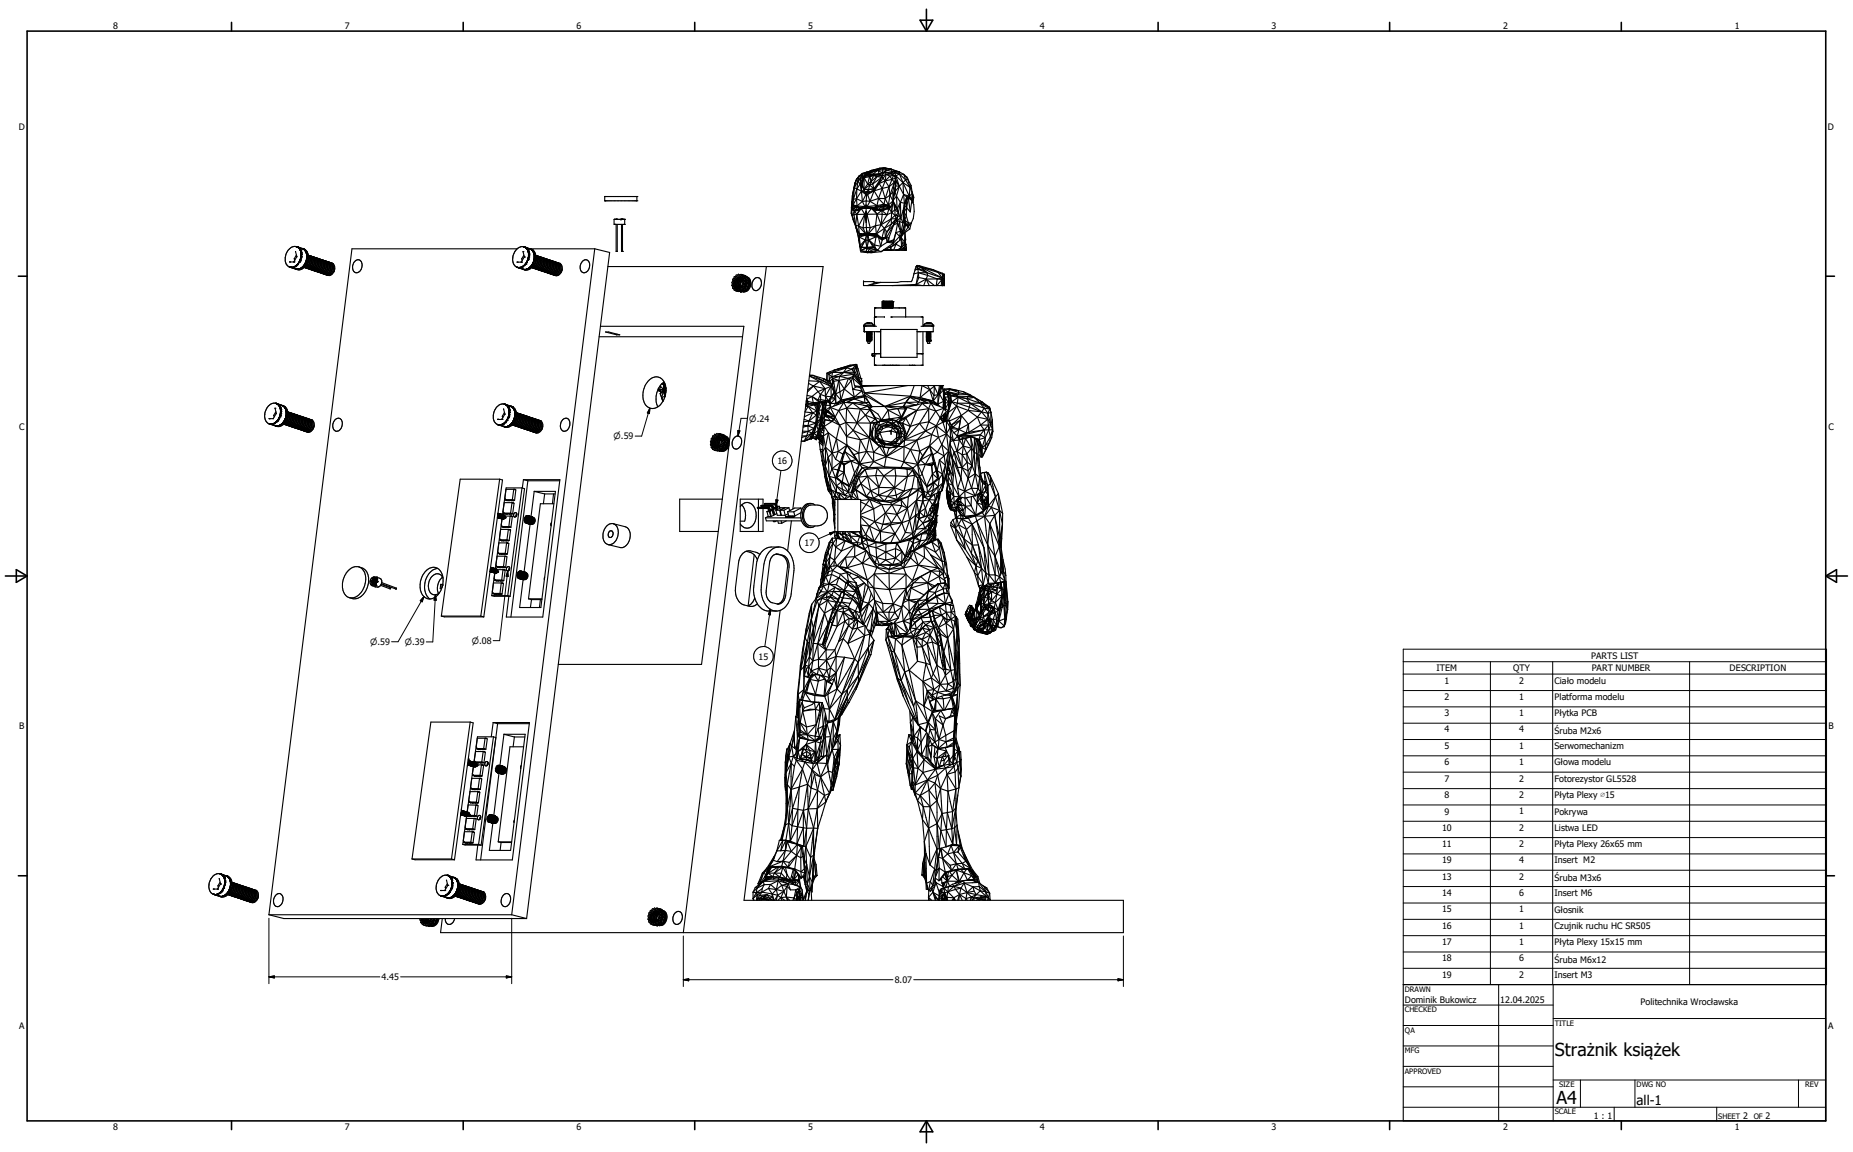
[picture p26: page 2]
SHEET 2 OF 2; DRAWN; CHECKED; MFG; APPROVED; Dominik Bukowicz; DWG NO all-1; TITLE Strażnik książek; SIZE A4; SCALE; Politechnika Wrocławska; REV; PARTS LIST; ITEM; QTY; PART NUMBER; DESCRIPTION; Ciało modelu; Platforma modelu; Płytka PCB; Śruba M2x6; Serwomechanizm; Głowa modelu; Fotorezystor GL5528; Płyta Plexy ∅15; Pokrywa; Listwa LED; Płyta Plexy 26x65 mm; Insert M2; Śruba M3x6; Insert M6; Głosnik; Czujnik ruchu HC SR505; Płyta Plexy 15x15 mm; Śruba M6x12; Insert M3

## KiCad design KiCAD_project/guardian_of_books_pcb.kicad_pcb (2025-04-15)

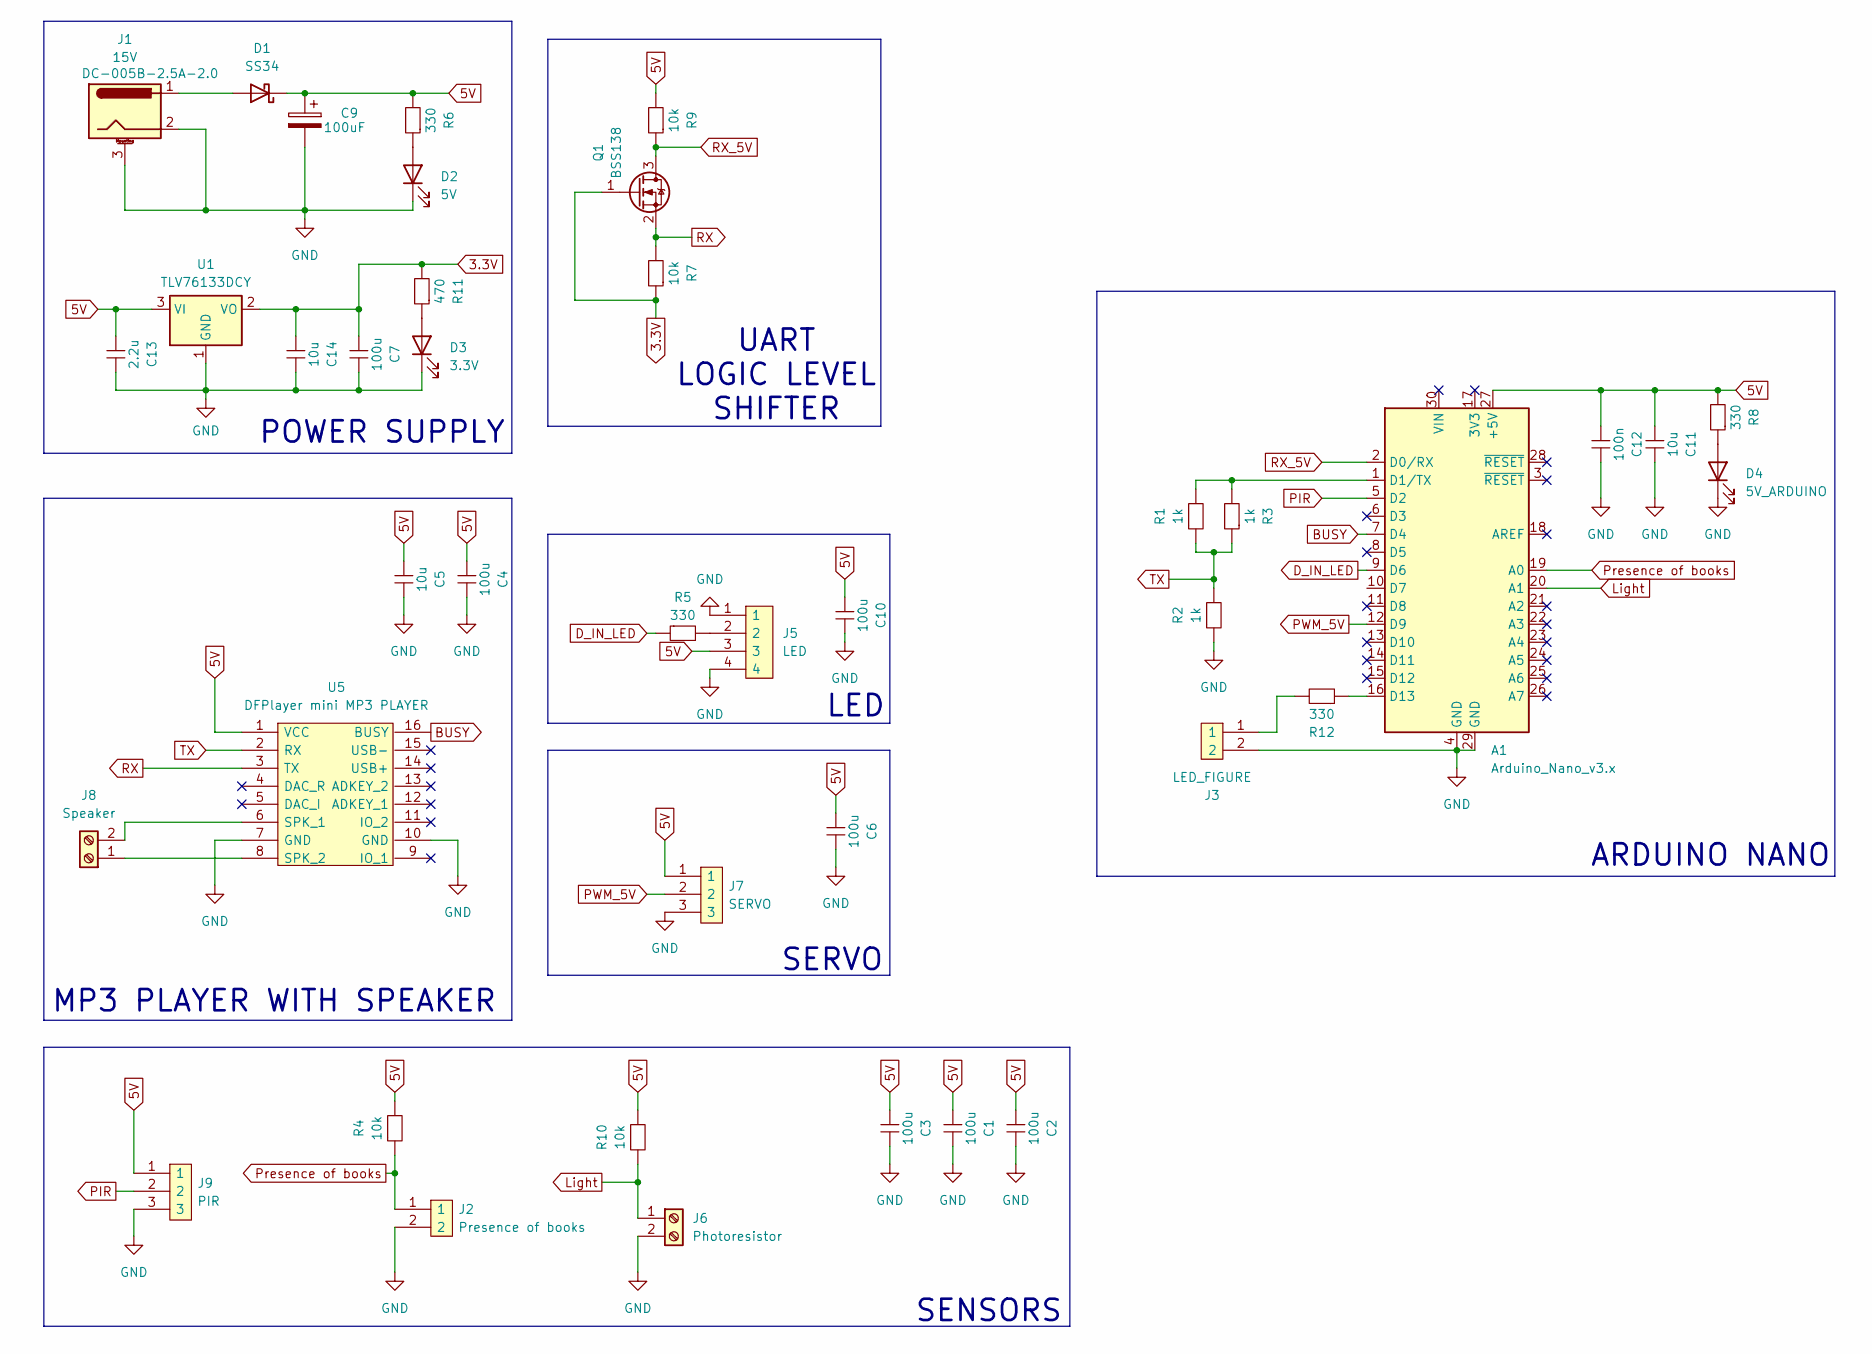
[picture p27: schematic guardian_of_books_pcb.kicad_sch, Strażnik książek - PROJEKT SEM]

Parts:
A1: Arduino_Nano_v3.x; Arduino_Nano
C1, C2, C3, C4, C6, C7, C10: 100u; cap_0603
C5, C11, C14: 10u; cap_0603
C9: 100uF; CP_Elec_6.3x7.7
C12: 100n; cap_0603
C13: 2.2u; cap_0603
D1: SS34; D_SMA
D2: 5V; LED_SMD
D3: 3.3V; LED_SMD
D4: 5V_ARDUINO; LED_SMD
J1: 15V; BarrelJack_Horizontal
J2: Presence of books; pin_con_2_female; Mouser Part Number 710-61300811821
J3: LED_FIGURE; pin_con_2_female; Mouser Part Number 710-61300811821
J5: LED; pin_con_4_female; Mouser Part Number 710-61300811821
J6: Photoresistor; screw_conector
J7: SERVO; pin_con_e_female; Mouser Part Number 710-61300811821
J8: Speaker; screw_conector
J9: PIR; pin_con_e_female; Mouser Part Number 710-61300811821
Q1: BSS138; SOT-23
R1, R2, R3: 1k; res_0603
R4, R7, R9, R10: 10k; res_0603
R5, R6, R8, R12: 330; res_0603
R11: 470; res_0603
U1: TLV76133DCY; SOT-223-3_TabPin2
U5: DFPlayer mini MP3 PLAYER; Mouser Part Number 710-61300811821

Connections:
3.3V: C7.1, C14.1, Q1.1 (G), R7.1, R11.2, U1.2 (VO)
5V: A1.27 (+5V), C1.1, C2.1, C3.1, C4.1, C5.1, C6.1, C9.1, C10.1, C11.1, C12.1, C13.1, D1.1 (K), J5.3, J7.1, J9.1, R4.2, R6.2, R8.2, R9.2, R10.2, U1.3 (VI), U5.1 (VCC)
BUSY: A1.7 (D4), U5.16 (BUSY)
D_IN_LED: A1.9 (D6), R5.1
GND: A1.4 (GND), A1.29 (GND), C1.2, C2.2, C3.2, C4.2, C5.2, C6.2, C7.2, C9.2, C10.2, C11.2, C12.2, C13.2, C14.2, D2.1 (K), D3.1 (K), D4.1 (K), J1.2, J1.3 (MountPin), J2.2, J3.2, J5.1, J5.4, J6.2, J7.3, J9.3, R2.1, U1.1 (GND), U5.7 (GND), U5.10 (GND)
Light: A1.20 (A1), J6.1, R10.1
unnamed: A1.1 (D1/TX), R1.2, R3.2
unnamed: A1.16 (D13), R12.1
unnamed: D1.2 (A), J1.1
unnamed: D2.2 (A), R6.1
unnamed: D3.2 (A), R11.1
unnamed: D4.2 (A), R8.1
unnamed: J3.1, R12.2
unnamed: J5.2, R5.2
unnamed: J8.1, U5.8 (SPK_2)
unnamed: J8.2, U5.6 (SPK_1)
PIR: A1.5 (D2), J9.2
PWM_5V: A1.12 (D9), J7.2
Presence of books: A1.19 (A0), J2.1, R4.1
RX: Q1.2 (S), R7.2, U5.3 (TX)
RX_5V: A1.2 (D0/RX), Q1.3 (D), R9.1
TX: R1.1, R2.2, R3.1, U5.2 (RX)

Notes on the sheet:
MP3 PLAYER WITH SPEAKER
LED
ARDUINO NANO
SERVO
SENSORS
POWER SUPPLY
UART LOGIC LEVEL SHIFTER

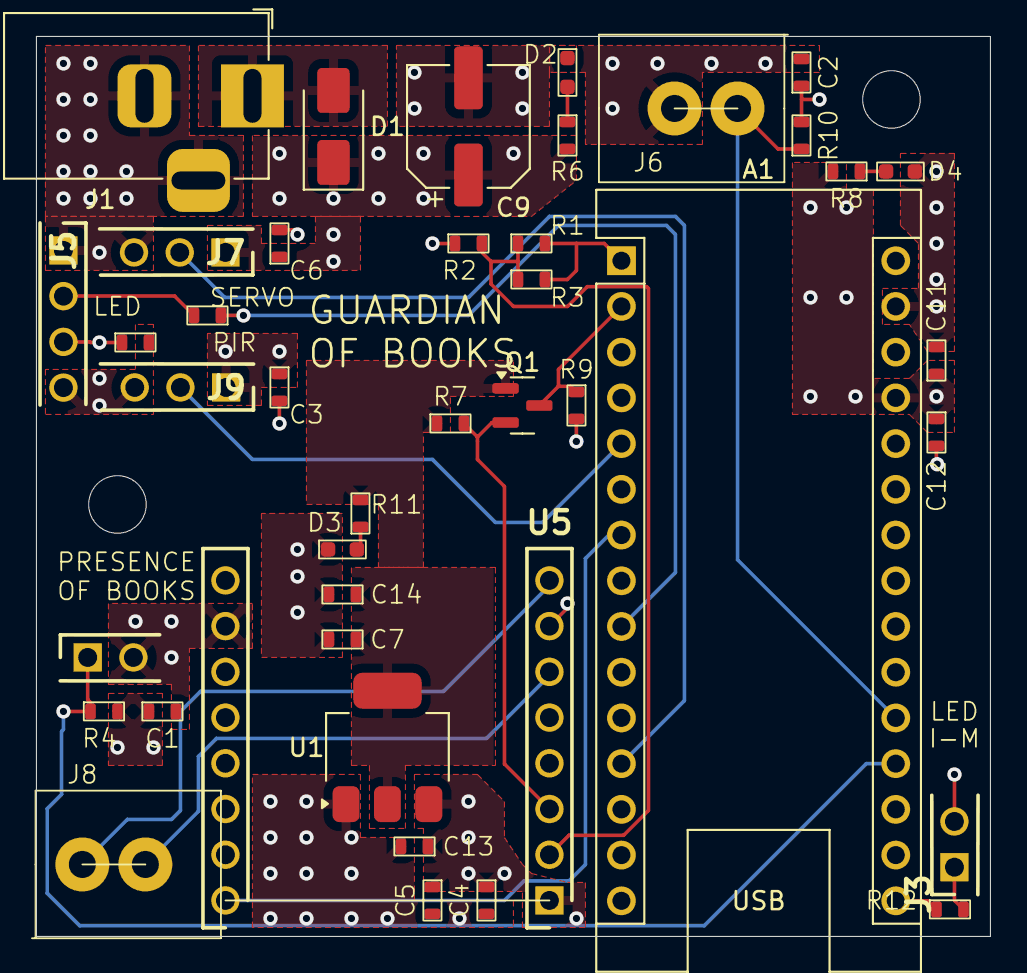
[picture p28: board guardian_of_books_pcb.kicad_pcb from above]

Board: 4 copper layers, 53.0 x 50.0 mm, 41 parts (0 on the bottom side), 22 nets.

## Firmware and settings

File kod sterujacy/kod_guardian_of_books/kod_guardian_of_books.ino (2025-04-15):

#include <Servo.h>                     // Biblioteka do obsługi serwomechanizmów
#include <Adafruit_NeoPixel.h>        // Biblioteka do obsługi paska LED NeoPixel
#include <DFRobotDFPlayerMini.h>      // Biblioteka do obsługi odtwarzacza DFPlayer Mini
#include <SoftwareSerial.h>           // Biblioteka do komunikacji szeregowej na dowolnych pinach

// === Piny ===
const int pinServo = 9;               // Pin, do którego podłączony jest serwomechanizm (np. "głowa")
const int pinLED = 6;                 // Pin danych paska LED
const int pinPIR = 2;                 // Pin czujnika ruchu PIR
const int pinDFPlayerRX = 0;          // DFPlayer TX → Arduino RX (pin 0)
const int pinDFPlayerTX = 1;          // DFPlayer RX → Arduino TX (pin 1)
const int pinDFPlayerBusy = 4;        // Pin informujący, czy DFPlayer odtwarza dźwięk
const int pinBookSensor = A0;         // Pin analogowy czujnika obecności książek
const int pinLightSensor = A1;        // Pin analogowy czujnika natężenia światła
const int pinDebugLED = 13;           // Wbudowana dioda LED do testowania

// === Moduły ===
Servo headServo;                      // Obiekt serwa
Adafruit_NeoPixel strip = Adafruit_NeoPixel(16, pinLED, NEO_GRB + NEO_KHZ800); // Pasek LED z 16 diodami
DFRobotDFPlayerMini dfplayer;         // Obiekt DFPlayera
SoftwareSerial mySerial(pinDFPlayerRX, pinDFPlayerTX); // Komunikacja z DFPlayerem na innych pinach

// === Parametry ===
const unsigned long motionTimeout = 5000;  // Czas bezruchu po którym system się wyłącza (ms)
const int dfFolder = 1;                    // Folder z plikami dźwiękowymi na karcie SD
const int numSounds = 5;                   // Liczba dostępnych dźwięków (plików)

unsigned long lastMotionTime = 0;          // Czas ostatniego wykrycia ruchu
bool systemActive = false;                 // Czy system jest aktywny

// === Inicjalizacja ===
void setup() {
  // Ustawienie trybu pracy pinów
  pinMode(pinPIR, INPUT);
  pinMode(pinDFPlayerBusy, INPUT);
  pinMode(pinBookSensor, INPUT);
  pinMode(pinLightSensor, INPUT);
  pinMode(pinDebugLED, OUTPUT);

  headServo.attach(pinServo);             // Podłączenie serwa do pinu
  headServo.write(0);                     // Ustawienie serwa w pozycji początkowej (0°)

  strip.begin();                          // Inicjalizacja paska LED
  strip.show();                           // Wyłączenie wszystkich diod

  mySerial.begin(9600);                   // Start komunikacji z DFPlayerem
  dfplayer.begin(mySerial);              // Inicjalizacja DFPlayera
  dfplayer.volume(25);                   // Ustawienie głośności (0–30)

  randomSeed(analogRead(A1));            // Inicjalizacja generatora losowego, jako źródło użyto czujnika światła

  digitalWrite(pinDebugLED, LOW);        // Zgaszenie diody debugującej
}

// === Główna pętla programu ===
void loop() {
  // Odczyt stanu czujników
  bool motionDetected = digitalRead(pinPIR);                         // Czy wykryto ruch
  bool booksPresent = analogRead(pinBookSensor) > 100;              // Czy są książki (czujnik aktywny powyżej progu)
  bool isDaylight = analogRead(pinLightSensor) > 300;              // Czy jest jasno (światło dzienne)

  // Jeśli wykryto ruch i są książki – aktywuj system
  if (motionDetected && booksPresent) {
    lastMotionTime = millis();              // Zapisz czas ostatniego ruchu
    if (!systemActive) {
      activateSystem(isDaylight);          // Jeśli system był nieaktywny – uruchom go
    }
  }

  // Jeśli system jest aktywny, ale nie było ruchu przez 5s – wyłącz
  if (systemActive && (millis() - lastMotionTime > motionTimeout)) {
    deactivateSystem();
  }
}

// === Aktywacja systemu (po wykryciu ruchu i obecności książek) ===
void activateSystem(bool isDaylight) {
  systemActive = true;                     // Oznacz system jako aktywny

  if (!isDaylight) {                       // Jeśli jest ciemno – włącz LEDy
    for (int i = 0; i < strip.numPixels(); i++) {
      strip.setPixelColor(i, strip.Color(255, 80, 0)); // Ciepły pomarańczowy kolor
    }
    strip.show();                          // Wyświetl kolory na pasku LED
  }

  headServo.write(90);                     // Obróć serwo (np. „głowa” do przodu)
  delay(500);                              // Poczekaj na pełen obrót

  playRandomSound();                       // Odtwórz losowy dźwięk z DFPlayera

  delay(3000);                             // Poczekaj na zakończenie odtwarzania (lub minimum 3 sekundy)

  headServo.write(0);                      // Cofnij serwo do pozycji początkowej
  delay(500);
}

// === Dezaktywacja systemu (po czasie bez ruchu) ===
void deactivateSystem() {
  systemActive = false;                    // Oznacz system jako nieaktywny

  // Zgaś wszystkie LEDy
  for (int i = 0; i < strip.numPixels(); i++) {
    strip.setPixelColor(i, 0);
  }
  strip.show();

  headServo.write(0);                      // Cofnij serwo na start
}

// === Funkcja do odtwarzania losowego dźwięku z DFPlayera ===
void playRandomSound() {
  int trackNumber = random(1, numSounds + 1); // Wybierz losowy numer od 1 do numSounds
  dfplayer.playFolder(dfFolder, trackNumber); // Odtwórz plik z podfolderu na karcie SD
}
